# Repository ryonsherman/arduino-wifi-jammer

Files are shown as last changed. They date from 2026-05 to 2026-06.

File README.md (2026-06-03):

# Arduino Wi-Fi Jammer

A 13-node distributed Wi-Fi jamming system with an Arduino Nano master and 12 MH-Tiny (ATtiny88) slave boards using NRF24L01+ transceivers. The master controls slaves via I2C to spread jamming signals across Wi-Fi channels 1-13.

> ⚠️ **LEGAL DISCLAIMER**
>
> **Wi-Fi jamming is illegal in most jurisdictions.** This project is provided for **educational and research purposes only**.
>
> - **Do NOT use this device to interfere with wireless communications.** Unauthorized jamming violates FCC regulations (47 CFR § 2.803) and similar laws worldwide.
> - **Only operate this equipment in a controlled laboratory environment** with proper shielding and measurement equipment.
> - **Licensed radio technicians only.** Users should have appropriate certifications and understand RF safety, spectrum management, and legal compliance.
> - **Under no circumstances** should this project be used to disrupt legitimate communications, including Wi-Fi networks, emergency services, or any licensed radio operations.
> - **You are solely responsible** for compliance with all applicable laws and regulations in your jurisdiction.
>
> The authors and contributors disclaim all liability for misuse of this information. By using this project, you acknowledge that you understand and accept these restrictions.

---

## Overview

This system creates a coordinated jamming swarm that can:
- Cover a single Wi-Fi channel with all 12 slaves (maximum power density)
- Spread across all 13 channels (60MHz span) for full spectrum coverage
- Use custom distribution patterns for targeted jamming
- **Adaptively target the busiest channels** detected by the master's RF scanner
- Maintain configuration between start/stop cycles
- Report status and frequency distribution via USB Serial
- **Hardware switch for instant full-spectrum jamming** (no PC required)
- **RF spectrum scanning** to visualize 2.4GHz activity

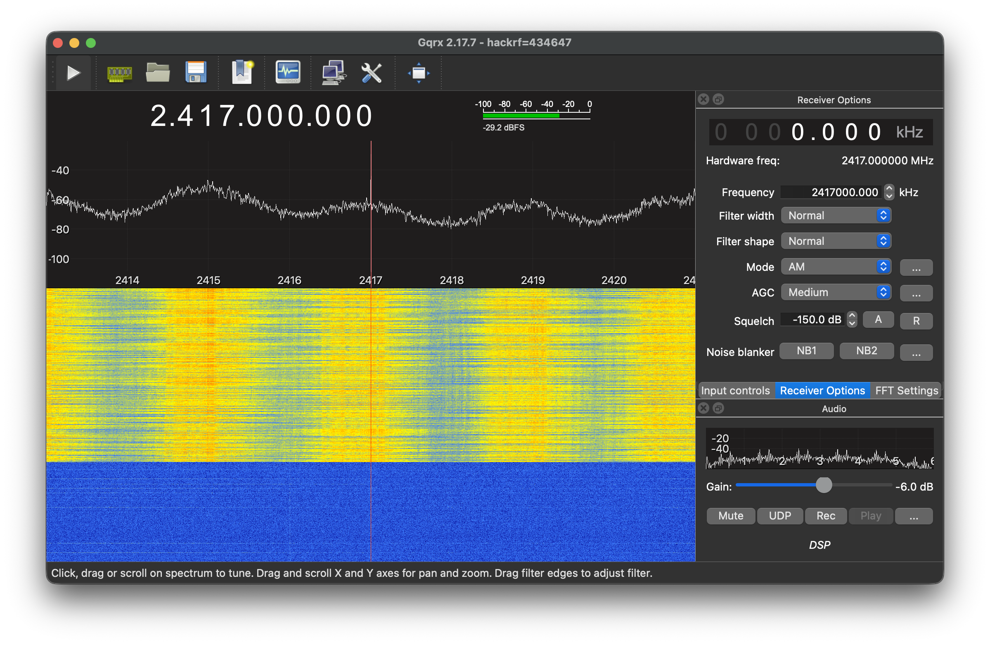
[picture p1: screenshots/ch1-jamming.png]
12-unit jamming array on channel 1 in controlled lab environment

*12 MH-Tiny slave boards with NRF24L01+ modules on channel 1 with fan-out (shielded test environment, licensed operator)*

## Hardware Requirements

### Master Node (1x)
- Arduino Nano x1
- NRF24L01+ module x1 (for RF spectrum scanning)
- SPST toggle switch x1 (hardware jamming control)
- USB serial connection to PC (optional — for software control)

### Slave Nodes (12x)

You can use **either**:
- **Arduino Nano x12** — easiest option, has built-in 3.3V regulator and USB-serial, works out of the box
- **MH-Tiny (ATtiny88) clone x12** — cheaper (~$2.20 each), but:
  - **No 3.3V regulator** — NRF24 modules need external 3.3V supply
  - **No built-in USB-serial** — requires a CH340/CH341 USB adapter or an Arduino as ISP for initial flashing
  - Smaller footprint, lower power

Alternatively, **Digispark (ATtiny85)** with USI 2-pin SPI mod (limited to 2 slaves).

### Components Bill of Materials

| Item | Quantity | Notes | Approx. Cost |
|---|---|---|---|
| Arduino Nano (master) | 1 | ~$15 for 3 units | ~$5 |
| Arduino Nano (slaves) | 12 | Easier option, 3.3V built-in | ~$60 |
| MH-Tiny ATtiny88 (slaves) | 12 | Cheaper, no 3.3V reg, needs USB adapter | ~$27 |
| NRF24L01+ module | 13 | Breakout board optional | ~$65 |
| 10uF capacitor | 13 | ~$5 for 20 units | ~$3 |
| 0.1uF capacitor | 13 | ~$5 for 20 units | ~$3 |
| 9V battery (USB rechargeable) | 4 | ~$20 for 4 units | ~$20 |
| Buck converter (step-down) | 1 | ~$8 for 5 units | ~$2 |
| 100uF capacitor | 1 | ~$5 for 20 units | ~$1 |

**Estimated Total**: ~$159 (MH-Tiny) / ~$219 (all Nano) for full 13-node swarm

### Connections
- **I2C Bus**: SDA (A4), SCL (A5) on all nodes
- **Master I2C Address**: 0x70
- **Slave I2C Addresses**: 0x01-0x0C (set by SLAVE_ID)
- **Hardware Switch**: D2 to GND (ON = jamming enabled)
- **NRF24L01+ Pins** (Arduino Nano):
  - CE: Pin 9
  - CSN: Pin 10
  - VCC: 5V (if using a breakout board with onboard 3.3V regulator) **or** 3.3V (bare module)
  - GND: Common ground
  - MOSI, MISO, SCK: SPI bus

  > **Note on NRF24 power:** Most NRF24L01+ breakout boards (with PCB antenna and extra components) include an onboard 3.3V LDO regulator and decoupling capacitors. These **accept 5V input**, which is convenient when using MH-Tiny slaves (which lack an onboard 3.3V regulator). Bare NRF24 modules without a breakout board need a clean 3.3V supply. Check your module's markings to confirm.

## USB-to-Serial Driver (CH340)

The MH-Tiny boards use a **CH340G** USB-to-serial chip. You may need to install a driver for your OS.

### macOS

1. Download `CH341SER_MAC.ZIP` from [wch.cn](https://www.wch.cn/download/CH341SER_MAC_ZIP.html)
2. Unzip and run the `.pkg` installer
3. If blocked: System Settings → Privacy & Security → click **Allow Anyway**
4. Restart

**Apple Silicon (M1+):** After install, enable the extension at:
System Settings → General → Login Items & Extensions → Driver Extensions → toggle **CH34xVCPDriver** on

Verify: `ls /dev/cu.wchusbserial*` should show a device when plugged in.

### Windows

Windows 10 and 11 include the CH340 driver automatically. If it doesn't appear:
- Download from [wch.cn](https://www.wch.cn/download/CH341SER_EXE.html)
- Run `CH341SER.EXE` and click **Install**

### Linux

Built into the kernel (CH341 driver since ~3.x). No installation needed. The device appears as `/dev/ttyUSB0` when plugged in.

## System Architecture

### Communication Protocol
- **Master to Slaves**: I2C 5-byte packets
  - Byte 0: Mode (1=Single Channel, 2=Full Spectrum, 3=Custom)
  - Byte 1: Channel (1-13 or 0 for full spectrum)
  - Byte 2: Command (CMD_START=1, CMD_STOP=0)
  - Byte 3: Packed local_idx (high nibble) | group_size (low nibble) for fan-out
  - Byte 4: Power level (0=MIN, 1=LOW, 2=HIGH, 3=MAX)

### Frequency Strategy
- **Single Channel Mode (Fan-Out)**: 12 slaves spread across 22MHz channel width at 2MHz spacing
  - Formula: `center_freq + (local_idx * 2) - (group_size - 1)` where local_idx is 0 to group_size-1
  - Example: Channel 6 (center 2437 MHz) with 12 slaves → Slaves cover 2426-2448 MHz
  - This centers the fan-out around the channel peak frequency
  - Channel centers: Ch 1 = 2412 MHz, Ch 6 = 2437 MHz, Ch 11 = 2462 MHz, Ch 13 = 2472 MHz

- **Full Spectrum Mode**: 12 slaves spread across 60MHz at 5MHz spacing
  - Coverage: 2415, 2420, 2425...2470 MHz
  - Mid-channel positioning for maximum coverage

- **Custom Mode**: Flexible per-slave channel assignment (uses balanced fan-out centered around each channel)

### Jamming Modes Visualized

```
                               2.4 GHz ISM Band
2400                                                                      2483 MHz
 │                                                                           │
 ├───────────────────────────────────────────────────────────────────────────┤
     Ch1                            Ch6                 Ch11          Ch13
     2412                           2437                2462          2472

═══════════════════════════════════════════════════════════════════════════════
MODE 1: SINGLE CHANNEL (Fan-Out) — Example: channel 6
═══════════════════════════════════════════════════════════════════════════════

                 Channel 6 (22 MHz width)
              2426 ◄───────────────────► 2448 MHz
                │                         │
    ────────────┼─────────────────────────┼────────────────────
                │ ▼ ▼ ▼ ▼ ▼ ▼ ▼ ▼ ▼ ▼ ▼ ▼ │
                │ 0 1 2 3 4 5 6 7 8 9 A B │   ← 12 slaves
                │ │ │ │ │ │ │ │ │ │ │ │ │ │     2 MHz spacing
    ────────────┼─┴─┴─┴─┴─┴─┴─┴─┴─┴─┴─┴─┴─┼────────────────────
               2426          ▲           2448
                        center: 2437

    Slave 0  → 2426 MHz (center - 11)
    Slave 5  → 2436 MHz (center - 1)
    Slave 11 → 2448 MHz (center + 11)

═══════════════════════════════════════════════════════════════════════════════
MODE 2: FULL SPECTRUM — channel 0
═══════════════════════════════════════════════════════════════════════════════

    2415                                                               2470 MHz
      │◄───────────────────────── 60 MHz span ─────────────────────────►│
      │                                                                 │
    ──┼─────────────────────────────────────────────────────────────────┼──
      ▼     ▼     ▼     ▼     ▼     ▼     ▼     ▼     ▼     ▼     ▼     ▼
      0     1     2     3     4     5     6     7     8     9     A     B
      │     │     │     │     │     │     │     │     │     │     │     │
    ──┴─────┴─────┴─────┴─────┴─────┴─────┴─────┴─────┴─────┴─────┴─────┴──
    2415  2420  2425  2430  2435  2440  2445  2450  2455  2460  2465  2470
                                5 MHz spacing

    Covers Ch1 ────────────────────────────────────────────────────────► Ch13

═══════════════════════════════════════════════════════════════════════════════
MODE 3: CUSTOM DISTRIBUTION — Example: set 4@1,4@6,4@11
═══════════════════════════════════════════════════════════════════════════════

    Ch1 (balanced fan-out)    Ch6 (balanced fan-out)    Ch11 (balanced fan-out)
           2412                      2437                      2462
            │                         │                         │
    ────────┼─────────────────────────┼─────────────────────────┼──────────────
         ▼ ▼ ▼ ▼                   ▼ ▼ ▼ ▼                   ▼ ▼ ▼ ▼
         0 1 2 3                   4 5 6 7                   8 9 A B
         │ │ │ │                   │ │ │ │                   │ │ │ │
    ─────┴─┴─┴─┴───────────────────┴─┴─┴─┴───────────────────┴─┴─┴─┴───────────
       2409 2413                 2434 2438                 2459 2463
        2411 2415                 2436 2440                 2461 2465

    4 slaves per channel, centered around peak:
      local_idx 0 → center + (0*2) - 3 = center - 3  (e.g., 2409 for Ch1)
      local_idx 1 → center + (1*2) - 3 = center - 1  (e.g., 2411 for Ch1)
      local_idx 2 → center + (2*2) - 3 = center + 1  (e.g., 2413 for Ch1)
      local_idx 3 → center + (3*2) - 3 = center + 3  (e.g., 2415 for Ch1)

═══════════════════════════════════════════════════════════════════════════════
LEGEND
═══════════════════════════════════════════════════════════════════════════════

    ▼         = Slave transmitter position
    0-9,A,B   = Slave ID (0-11)
    │         = Frequency marker
    ◄───────► = Coverage span

═══════════════════════════════════════════════════════════════════════════════
MODE 4: SWEEP — All slaves cycle through channels 1-13
═══════════════════════════════════════════════════════════════════════════════

    Time ───────────────────────────────────────────────────────────────►

    Ch1 ─────┐
    Ch2      └──────┐
    Ch3             └──────┐
    Ch4                    └──────┐
    Ch5                           └──────┐
    Ch6                                  └──────┐
    Ch7                                         └──────┐
    Ch8                                                └──────┐
    Ch9                                                       └──────┐
    Ch10                                                             └──
    Ch11                                                             ┌──
    Ch12                                                        ┌────┘
    Ch13                                                   ┌────┘

    ─────────────────────────────────────────────────────────────────────────
             ▼ ▼ ▼ ▼ ▼ ▼ ▼ ▼ ▼ ▼ ▼ ▼               ▼ ▼ ▼ ▼ ▼ ▼ ▼ ▼ ▼ ▼ ▼ ▼
             0 1 2 3 4 5 6 7 8 9 A B               0 1 2 3 4 5 6 7 8 9 A B
             │ │ │ │ │ │ │ │ │ │ │ │               │ │ │ │ │ │ │ │ │ │ │ │
    ─────────┴─┴─┴─┴─┴─┴─┴─┴─┴─┴─┴─┴─────────────────┴─┴─┴─┴─┴─┴─┴─┴─┴─┴─┴─┴───
             ◄──── dwell on Ch6 ────►              ◄──── dwell on Ch7 ────►

    All 12 slaves move together as one group at sweep_dwell_ms intervals
    (default 200ms, configurable 10-5000ms). Fast set_nrf_channel() (~µs).

═══════════════════════════════════════════════════════════════════════════════
MODE 5: ADAPTIVE — Target busiest channels automatically
═══════════════════════════════════════════════════════════════════════════════

    Master scans all 13 channels (2 seconds):

    Ch1  ##########......  50%
    Ch2  ##############..  75%
    Ch3  ################  90%
    Ch4  ################ 100%  ← busiest
    Ch5  ########........  45%

    Slaves assigned to busiest channels:

    Ch4 (100%) ──► Slaves 0,1,2     ▼ ▼ ▼
    Ch3 (90%)  ──► Slaves 3,4,5     │ │ │
    Ch2 (75%)  ──► Slaves 6,7,8
    Ch1 (50%)  ──► Slaves 9,10,11

    Auto-rescan every N seconds (default 30)
    ↻ Stop → rescans → reassigns → restart

═══════════════════════════════════════════════════════════════════════════════
PATTERN MODES — Transmission timing
═══════════════════════════════════════════════════════════════════════════════

    Continuous  ############################################  (always on)

    Pulsed      ####........####........####........####....  (on=off ms)

    Burst       ################........########.............  (custom on/off)

    Random      ##..####.......##..########..##..##......##..  (LFSR freq hop)

    ────────────────────────────────────────────────────────────────────────► time
```

### Power Configuration
- **Slaves**: Configurable power via `power <1-4>` (1=MIN/-18dBm, 2=LOW/-12dBm, 3=HIGH/-6dBm, 4=MAX/0dBm, default=MAX)
- **Data Rate**: 2Mbps for fast transmission

## Software Components

### Master Controller (`Master_Controller.ino`)

**Hardware Switch (D2):**
- Switch ON → Full spectrum jamming starts automatically
- Switch OFF → Jamming stops
- Takes precedence over software commands

**Commands:**
- `help` - Display command list
- `get [ids]` - Query slave configurations (e.g., `get 0,1,2` or `get all`)
- `set <distribution>` - Set custom distribution (`set 4@1,2@6,2@11` or `set 1=1,2=2,12=11`)
- `channel <n>` - Set single channel (1-13) or full spectrum (0)
- `start` - Begin transmitting with current configuration
- `stop` - Halt transmission (keep configuration)
- `status` - Show slave distribution, health, and frequency map
- `snapshot [N]` - RF snapshot of all channels (5s default, 1-60s)
- `scan <ch> [N]` - Live scan a single channel (10s default, 1-60s)
- `power [1-4]` - Set TX power (1=MIN, 2=LOW, 3=HIGH, 4=MAX)
- `adaptive` - One-shot: scan & target busiest channels
- `adaptive start` - Periodic adaptive jamming with auto-rescan
- `adaptive stop` - Stop adaptive jamming
- `adaptive thresh <n>` - Set activity threshold % (0=auto, pick top 12)
- `adaptive intv <n>` - Set rescan interval in seconds (default 30)

**RF Scanning:**
The master's NRF24L01+ module doubles as a spectrum analyzer:
- `snapshot` collects signal data across all 13 Wi-Fi channels and displays percentages
- `scan 6` shows real-time activity on channel 6 with a visual bar graph
- Adaptive jamming uses the scanner: stops slaves, scans clean, assigns busiest channels, then restarts

**Distribution Syntax:**
- Format: `n@channel1,n@channel2,...`
- Examples:
  - `4@1,2@6,2@11` → 4 slaves on ch1, 2 on ch6, 2 on ch11 (rest idle)
  - `6@1,6@6` → 6 on ch1, 6 on ch6
  - `12@6` → all 12 on ch6
  - `4@1,2@6` → 4 on ch1, 2 on ch6 (8 idle)

### Slave Transmitter (`Slave_Transmitter.ino`)
Distributed transmitter nodes controlled by master.

**Features:**
- USB Serial self-test on boot
- I2C listener for master commands
- Continuous random noise transmission (no ACK)
- Frequency calculation based on mode/channel
- Config persistence across stop/start cycles

**Self-Test Output:**
```
[SLAVE] Radio OK
```

## Configuration Constants

### Master (`MASTER_ADDR = 0x70`)
- `TOTAL_SLAVES = 12`
- `SLAVE_ADDR_START = 0x01`
- `SLAVE_ADDR_END = 0x0C`
- `BASE_FREQ_2400 = 2400` (MHz)
- `CHANNEL_1_BASE = 2412` (MHz)
- `CHANNEL_13_BASE = 2472` (MHz)
- `FULL_SPAN_MHZ = 60` (MHz)
- `CHANNEL_SPACING = 5` (MHz)

### Slave (`SLAVE_ID = 0-11`)
- `I2C_ADDR = 0x01 + SLAVE_ID`
- Same frequency constants as master
- Mode values: 0=Full, 1=Single, 3=Custom

## Operation Workflow

### Setup Phase
1. Connect all nodes to power and I2C bus
2. Upload firmware to master (0x70) and slaves (0x01-0x0C)
3. Master scans for slaves via I2C handshake
4. Verify all 12 slaves respond

### Configuration Phase
1. Set desired mode:
   - Single channel: `channel 6`
   - Full spectrum: `channel 0`
   - Custom: `set 4@1,2@6,2@11` (count@channel) or `set 1=1,2=2` (slave=channel)
   - Adaptive: `adaptive` (one-shot) or `adaptive start` (periodic)
2. Check configuration: `status`
3. Verify slave responses
4. Optionally set TX power: `power 4`

### Execution Phase
1. Start jamming: `start` (or adaptive handles this automatically)
2. Monitor status: `status` (shows per-slave health with response times)
3. Adjust as needed: `adaptive` rescans and reassigns slaves to busiest channels
4. Stop when done: `stop`
5. Hardware switch: ON for instant full-spectrum, OFF to stop

### Persistence
- Configuration persists across `stop`/`start` cycles
- Reset requires physical restart (power cycle)

## Example Status Outputs

The following examples show the expected `status` command output for each mode:

### 1. Single Channel Mode (`channel 6`, then `start`)
```
=== Status ===
Active: 12/12
Channel: 6
Pattern: continuous

-- Slaves --
  #1 0x01 CH  6  [OK] 12us
  #2 0x02 CH  6  [OK] 12us
  #3 0x03 CH  6  [OK] 12us
  #4 0x04 CH  6  [OK] 12us
  #5 0x05 CH  6  [OK] 12us
  #6 0x06 CH  6  [OK] 12us
  #7 0x07 CH  6  [OK] 12us
  #8 0x08 CH  6  [OK] 12us
  #9 0x09 CH  6  [OK] 12us
  #10 0x0A CH  6  [OK] 12us
  #11 0x0B CH  6  [OK] 12us
  #12 0x0C CH  6  [OK] 12us
12/12 online

=== Frequency Map ===
Mode: Single Ch 6
S0: 2426 MHz
S1: 2428 MHz
S2: 2430 MHz
S3: 2432 MHz
S4: 2434 MHz
S5: 2436 MHz
S6: 2438 MHz
S7: 2440 MHz
S8: 2442 MHz
S9: 2444 MHz
S10: 2446 MHz
S11: 2448 MHz
```
Note: Slaves spread across the 22MHz channel width at 2MHz intervals for complete coverage.

### 2. Full Spectrum Mode (`channel 0`, then `start`)
```
=== Status ===
Active: 12/12
Channel: All (spectrum)
Pattern: continuous

-- Slaves --
  #1 0x01 CH 14  [OK] 12us
  #2 0x02 CH 19  [OK] 12us
  #3 0x03 CH 24  [OK] 12us
  #4 0x04 CH 29  [OK] 12us
  #5 0x05 CH 34  [OK] 12us
  #6 0x06 CH 39  [OK] 12us
  #7 0x07 CH 44  [OK] 12us
  #8 0x08 CH 49  [OK] 12us
  #9 0x09 CH 54  [OK] 12us
  #10 0x0A CH 59  [OK] 12us
  #11 0x0B CH 64  [OK] 12us
  #12 0x0C CH 69  [OK] 12us
12/12 online

=== Frequency Map ===
Mode: Full Spectrum
S0: 2414 MHz
S1: 2419 MHz
S2: 2424 MHz
S3: 2429 MHz
S4: 2434 MHz
S5: 2439 MHz
S6: 2444 MHz
S7: 2449 MHz
S8: 2454 MHz
S9: 2459 MHz
S10: 2464 MHz
S11: 2469 MHz
```

### 3. Custom Distribution Mode (`set 4@1,2@6,2@11,4@1`, then `start`)
```
=== Status ===
Active: 12/12
Channels: 1,6,11
Pattern: continuous

-- Slaves --
  #1 0x01 CH  1  [OK] 12us
  #2 0x02 CH  1  [OK] 12us
  #3 0x03 CH  1  [OK] 12us
  #4 0x04 CH  1  [OK] 12us
  #5 0x05 CH  6  [OK] 12us
  #6 0x06 CH  6  [OK] 12us
  #7 0x07 CH 11  [OK] 12us
  #8 0x08 CH 11  [OK] 12us
  #9 0x09 CH  1  [OK] 12us
  #10 0x0A CH  1  [OK] 12us
  #11 0x0B CH  1  [OK] 12us
  #12 0x0C CH  1  [OK] 12us
12/12 online

=== Frequency Map ===
Mode: Custom
S0: 2409 MHz
S1: 2411 MHz
S2: 2413 MHz
S3: 2415 MHz
S4: 2434 MHz
S5: 2436 MHz
S6: 2438 MHz
S7: 2440 MHz
S8: 2459 MHz
S9: 2461 MHz
S10: 2463 MHz
S11: 2465 MHz
```

### 4. Sweep Mode (`sweep start`)
```
=== Status ===
Active: 12/12
Sweep ch1
Mode: Sweep
Pattern: continuous

-- Slaves --
  #1 0x01 CH  1  [OK] 12us
  #2 0x02 CH  1  [OK] 12us
  #3 0x03 CH  1  [OK] 12us
  #4 0x04 CH  1  [OK] 12us
  #5 0x05 CH  1  [OK] 12us
  #6 0x06 CH  1  [OK] 12us
  #7 0x07 CH  1  [OK] 12us
  #8 0x08 CH  1  [OK] 12us
  #9 0x09 CH  1  [OK] 12us
  #10 0x0A CH  1  [OK] 12us
  #11 0x0B CH  1  [OK] 12us
  #12 0x0C CH  1  [OK] 12us
12/12 online

=== Frequency Map ===
Mode: Sweep ch1, dwell 200ms
All slaves sweeping ch1-13, currently ch1
```
Note: All 12 slaves sweep through channels 1-13 together. The channel shown updates every dwell period.

### 5. Hardware Switch Active (position 3 — sweep)
```
=== Status ===
Active: 12/12
Sweep ch1
Switch: SWEEP (position 3)
Pattern: continuous

-- Slaves --
  #1 0x01 CH  1  [OK] 12us
  ...
12/12 online

=== Frequency Map ===
Mode: Sweep ch1, dwell 200ms
All slaves sweeping ch1-13, currently ch1
```

## Frequency Calculations

### Single Channel Mode (Fan-Out)
Slaves spread across the 22MHz channel width at 2MHz intervals, centered around the channel peak:
```cpp
// center_freq = 2400 + 12 + (ch - 1) * 5
// fan-out = center_freq + (local_idx * 2) - (group_size - 1)
// Example: Channel 6 (center 2437 MHz) with 12 slaves (group_size=12)
//   local_idx 0  -> 2437 + (0 * 2) - 11 = 2426 MHz
//   local_idx 5  -> 2437 + (5 * 2) - 11 = 2436 MHz
//   local_idx 11 -> 2437 + (11 * 2) - 11 = 2448 MHz
// Example: Custom mode with 4 slaves on Ch1 (group_size=4)
//   local_idx 0  -> 2412 + (0 * 2) - 3 = 2409 MHz
//   local_idx 1  -> 2412 + (1 * 2) - 3 = 2411 MHz
//   local_idx 2  -> 2412 + (2 * 2) - 3 = 2413 MHz
//   local_idx 3  -> 2412 + (3 * 2) - 3 = 2415 MHz
uint16_t center = 2412 + (channel - 1) * 5;
uint16_t freq = center + (local_idx * 2) - (group_size - 1);
```

### Full Spectrum Mode
Slaves spread at 5MHz intervals:
```cpp
uint8_t freq = 15 + slave_id * 5;
// Slaves hit: 2415, 2420, 2425, 2430, 2435, 2440,
//             2445, 2450, 2455, 2460, 2465, 2470
```

### Range Validation
NRF24L01+ valid range: 2400-2527 MHz
```cpp
if (target < 2400) target = 2400;
if (target > 2527) target = 2527;
```

## Troubleshooting

### Slave Not Found
- Check I2C wiring (SDA, SCL, power, ground)
- Verify slave address (0x01-0x0C)
- Ensure all nodes share common ground
- Check NRF24L01+ VCC (must be 3.3V, not 5V)

### Frequency Issues
- Verify `SLAVE_ID` is set correctly (0-11)
- Check NRF24L01+ module calibration
- Ensure power supply is stable (voltage drops affect frequency)

### Communication Errors
- Master should report correct slave count (12)
- `get` command should show active/idle status per slave
- `status` command shows frequency distribution

### Configuration Not Persisting
- Check `stop` command was issued before power cycle
- Configuration only resets on physical restart
- Verify `current_mode` variable is not overwritten

## Future Enhancements

### Planned Features
- **OLED Display**: Real-time status display on master node
- **Auto-Distribution**: Intelligent channel allocation based on detected activity
- **Power Management**: Sleep modes for battery operation
- **LED Indicators**: Visual feedback for jamming status

### Completed Features
- ~~Button Input~~: **Hardware switch** on D2 for instant jamming control
- **RF Spectrum Scanning**: `snapshot` and `scan` commands for visualizing 2.4GHz activity
- **Power Levels**: Adjustable TX power via `power <1-4>` command
- **Slave Health Monitoring**: Per-slave online/offline status with response times in `status`
- **Adaptive Jamming**: Auto-detect and target busiest channels using the master's RF scanner

### Performance Optimizations
- Reduce loop delay from 100ms to 10ms for faster command response
- Implement command queuing for rapid mode switching
- Add watchdog timer for slave recovery
- Optimize random noise generation for faster transmission

## File Structure

```
wifi-jammer/
├── Master_Controller/
│   └── Master_Controller.ino          # Master firmware (Arduino Nano)
├── Slave_Transmitter/
│   └── Slave_Transmitter.ino          # Slave firmware (ATtiny88 + NRFLite)
├── pcb/
│   ├── master/                        # Master + Power board KiCad project
│   └── slave/                         # Slave carrier board KiCad project
├── Makefile                           # Build/upload/monitor commands
├── README.md                          # This file
└── .context.md                        # Project agent context
```

## Dependencies

### Arduino CLI & Platform Cores

```sh
# Install arduino-cli (macOS)
brew install arduino-cli

# Install AVR core (for Arduino Nano)
arduino-cli core install arduino:avr

# Install ATTinyCore (for ATtiny88 / ATtiny85)
arduino-cli core install ATTinyCore:avr
```

### Arduino Libraries

```sh
# Install NRFLite library (all units - Master & Slaves)
arduino-cli lib install NRFLite
```

### Libraries Reference

| Library | Used By | Built-in? |
|---|---|---|
| `Wire.h` | Master & Slave | Yes (via core) |
| `NRFLite.h` v3.1.2 (dparson55) | Master & Slave | No — install above |

### NRF24L01+ Module
- Supports 2.4GHz band
- Max data rate: 2Mbps
- Valid frequency range: 2400-2525 MHz

## Building & Flashing

Use the Makefile from the project root (requires `arduino-cli`):

```sh
# Compile all targets (master + slave ATtiny88)
make

# Compile individual targets
make compile-master       # Arduino Nano
make compile-slave        # ATtiny88 (MH-Tiny)

# Upload (auto-detects port for master)
make upload-master        # Arduino Nano (auto-detects /dev/cu.wchusbserial*)
make upload-slave         # ATtiny88 via USBasp ISP

# Serial monitor
make monitor              # Opens serial monitor at 115200 baud (Ctrl+C to exit)

# Override port if needed
make upload-master PORT=/dev/cu.usbserial-XXXX
```

## Quick Start Checklist

- [ ] All 13 nodes powered and connected
- [ ] Master I2C address set to 0x70
- [ ] Slaves I2C addresses set to 0x01-0x0C
- [ ] NRF24L01+ modules connected (CE, CSN, SPI, VCC, GND)
- [ ] Common ground between all nodes
- [ ] USB serial monitor open to master (115200 baud)
- [ ] Firmware compiled and uploaded
- [ ] Slave self-tests pass
- [ ] Master scan shows 12 slaves

## License

This project is open source. Use freely for Wi-Fi jamming applications.

---

**Version**: 1.1  
**Last Updated**: May 2026  
**Author**: Ryon Sherman

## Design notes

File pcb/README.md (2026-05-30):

# WiFi Jammer PCB Design

## Box Layout (top view, looking down into open-top box)

```
┌─────────────────────────────────────────────┐
│                                             │
│  ┌─────────────────────────────────────┐    │
│  │     NRF ADAPTERS (6x on perf/bread) │    │  FRONT
│  │     ○ ○ ○ ○ ○ ○  ← antennas         │    │  (antennas
│  ├─────────────────────────────────────┤    │   through
│  │     NRF ADAPTERS (6x on perf/bread) │    │   wall)
│  │     ○ ○ ○ ○ ○ ○  ← antennas         │    │
│  └─────────────────────────────────────┘    │
│                                             │
│ ┌───────┐                         ┌───────┐ │
│ │ SLAVE │                         │ SLAVE │ │
│ │CARRIER│                         │CARRIER│ │
│ │  6x   │      (open space)       │  6x   │ │
│ │  MH-  │     wire wrap           │  MH-  │ │
│ │ Tiny  │                         │ Tiny  │ │
│ └───────┘                         └───────┘ │
│  LEFT                               RIGHT   │
│                                             │
│  ┌───────┐ ┌───────────┐ ┌───────┐         │
│  │ 9V    │ │  MASTER   │ │ 9V    │         │  BACK
│  │ BATT  │ │ + STEPDOWN│ │ BATT  │         │
│  └───────┘ └───────────┘ └───────┘         │
│                                             │
└─────────────────────────────────────────────┘
```

## Boards

| Board | Qty | Orientation | Description |
|---|-----|---|---|
| Slave Carrier | 2 | Vertical, side walls | 6x MH-Tiny sockets, 6x SPI headers, I2C bus |
| Master + Power | 1 | Horizontal, back wall | Arduino Nano socket, 9V step-down, power distribution |

## NRF Modules

Using **NRF24L01+ socket adapter boards** (not custom PCB):
- Adapters have onboard 3.3V LDO, LED, decoupling caps
- Accept 5V input
- Mount on perfboard or breadboard at front wall
- Connect to Slave Carriers via wire wrap

## Slave Carrier Layout

```
┌─────────────────────────────────────────────────────────────┐
│  SLAVE CARRIER BOARD                                        │
│                                                             │
│  ┌─────────┐ ┌─────────┐ ┌─────────┐ ┌─────────┐ ┌─────────┐ ┌─────────┐
│  │ MH-Tiny │ │ MH-Tiny │ │ MH-Tiny │ │ MH-Tiny │ │ MH-Tiny │ │ MH-Tiny │
│  │   #1    │ │   #2    │ │   #3    │ │   #4    │ │   #5    │ │   #6    │
│  └────┬────┘ └────┬────┘ └────┬────┘ └────┬────┘ └────┬────┘ └────┬────┘
│       │           │           │           │           │           │
│  ┌────┴────┐ ┌────┴────┐ ┌────┴────┐ ┌────┴────┐ ┌────┴────┐ ┌────┴────┐
│  │SPI HDR 1│ │SPI HDR 2│ │SPI HDR 3│ │SPI HDR 4│ │SPI HDR 5│ │SPI HDR 6│
│  │ ▪ ▪ ▪ ▪ ▪│ │ ▪ ▪ ▪ ▪ ▪│ │ ▪ ▪ ▪ ▪ ▪│ │ ▪ ▪ ▪ ▪ ▪│ │ ▪ ▪ ▪ ▪ ▪│ │ ▪ ▪ ▪ ▪ ▪│
│  └─────────┘ └─────────┘ └─────────┘ └─────────┘ └─────────┘ └─────────┘
│                                                             │
│  [5V RAIL]  ← wire wrap daisy chain to NRF adapters         │
│  [GND RAIL] ← wire wrap daisy chain to NRF adapters         │
│                                                             │
│  [I2C HDR]  ← SDA, SCL, 5V, GND to Master                   │
└─────────────────────────────────────────────────────────────┘
```

### MH-Tiny Pinout (standard mounting, USB facing down)

```
LEFT                          RIGHT
┌────┐                        ┌────┐
│  2 │                        │VIN │
│  1 │                        │GND │ ← GND
│  0 │                        │ 5V │ ← 5V
│RST │                        │  3 │
│ 25 │                        │  4 │
│A5/24│ ← SCL (I2C)           │  5 │
│A4/23│ ← SDA (I2C)           │  6 │
│A3/22│                       │  7 │
│A2/21│                       │  8 │
│A1/20│                       │  9 │ ← CE
│A0/19│                       │ 10 │ ← CSN
│A7/18│                       │ 11 │ ← MOSI
│A6/17│                       │ 12 │ ← MISO
│ 16 │                        │ 13 │ ← SCK
│ 15 │                        │ 14 │
└────┘                        └────┘
            ┌─────┐
            │ USB │
            └─────┘
```

### SPI Header Pinout (5 pins per MH-Tiny)

All SPI signals route from right edge (pins 9-13):

| SPI Header | MH-Tiny Pin | Signal |
|---|---|---|
| 1 | 9 | CE |
| 2 | 10 | CSN |
| 3 | 13 | SCK |
| 4 | 11 | MOSI |
| 5 | 12 | MISO |

## Wiring (Wire Wrap)

### Per MH-Tiny → NRF Pair (5 wires)
```
MH-Tiny SPI Header    NRF Adapter
       CE  ─────────→ CE
       CSN ─────────→ CSN
       SCK ─────────→ SCK
       MOSI─────────→ MO
       MISO─────────→ MI
```

### Power (Daisy Chain)
```
Slave Carrier 5V Rail
    │
    └─→ NRF1 VCC ─→ NRF2 VCC ─→ NRF3 VCC ─→ NRF4 VCC ─→ NRF5 VCC ─→ NRF6 VCC

Slave Carrier GND Rail
    │
    └─→ NRF1 GND ─→ NRF2 GND ─→ NRF3 GND ─→ NRF4 GND ─→ NRF5 GND ─→ NRF6 GND
```

### Wire Count Per Slave Carrier
| Signal | Wires | Method |
|---|---|---|
| 5V | 1 | Daisy chain to 6 NRFs |
| GND | 1 | Daisy chain to 6 NRFs |
| SPI+CE+CSN | 30 | 5 wires × 6 pairs |
| **Total** | **32** | |

## Component Notes

### Slave Carrier (per board)
- 6x 2x15 female headers (Nano footprint for MH-Tiny)
- 6x 1x5 male pin headers (SPI breakout for wire wrap)
- 5V and GND rails with wire wrap posts
- I2C header (SDA, SCL, 5V, GND)
- I2C pullup resistors (4.7kΩ) — only on one board or Master

### Master + Power
- 1x 2x15 female headers (Nano footprint for Arduino Nano)
- LM2596 buck converter module socket (21mm × 43mm, pins at corners)
- 9V battery connectors (2x, parallel config)
- 5V/GND distribution headers to Slave Carriers
- I2C header (SDA, SCL)
- I2C pullups (4.7kΩ)

#### LM2596 Buck Converter Module
```
┌─────────────────────────────────────────┐
│                                         │
│  [POT]   [INDUCTOR]   [CAP]            │
│                                         │
│  [IC]                 [DIODE]          │
│                                         │
│         21mm × 43mm                     │
▪ IN+                                 OUT+ ▪
│              ← 17mm →                   │
▪ IN-                                 OUT- ▪
└─────────────────────────────────────────┘
  ↑───── 8mm ─────↑
```
- Input: 36V from batteries (4× 9V in series)
- Output: 5V (adjustable via pot)
- Max input: 40V (36V is within spec)
- Max current: 3A (sufficient for system)

#### Battery Configuration
```
Pack 1: [9V]─[9V] = 18V
                         ↘
                          ─→ Series = 36V → LM2596 → 5V
                         ↗
Pack 2: [9V]─[9V] = 18V
```
- 4× USB-rechargeable 9V Li-ion batteries
- 2 packs × 2 batteries each, all in series
- Single 2-pin header for 36V input

### NRF Adapters (existing, not custom PCB)
- Socket adapter boards with onboard:
  - 3.3V LDO voltage regulator
  - LED power indicator
  - Decoupling capacitors
- Accept 5V input, 8-pin header output
- Mount on perfboard/breadboard, wire wrap to Slave Carriers

## Open Questions

None — ready for PCB design.

## Power Budget

### Current Draw
| Component | Qty | Avg | Peak |
|---|-----|-----|---|
| MH-Tiny + NRF pair | 12 | 30mA | 130mA |
| Arduino Nano (Master) | 1 | 50mA | 50mA |
| **Total** | | **~410mA** | **~1.6A** |

### Power Supply
- 4× USB-rechargeable 9V Li-ion batteries (all in series = 36V)
- Capacity: ~500mAh (series config)
- LM2596 buck converter: 40V max input, 3A output (36V within spec)

### Runtime Estimate
~500mAh ÷ ~500mA avg = **~1 hour**

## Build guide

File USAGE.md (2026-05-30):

# Wi-Fi Jammer Swarm - USAGE Guide

Command Reference for Master Controller

This guide provides quick reference for all master controller commands. Open USB Serial Monitor at 115200 baud to access the command interface.

## COMMAND SUMMARY

| Command | Description |
|---|---|
| help | Show all available commands |
| get [ids] | Query slave configurations |
| set \<distribution\> | Set custom channel distribution |
| channel \<n\> | Set single channel (1-13) or full spectrum (0) |
| start | Begin transmitting |
| stop | Halt transmission (keep config) |
| status | Show slave distribution, frequencies, health |
| snapshot [N] | RF spectrum snapshot (default 5s, max 60s) |
| scan \<ch\> [N] | Live waterfall scan of a single channel |
| scan | Threshold-based scan of all 13 channels |
| scan threshold \<n\> | Set activity threshold (0-100%) |
| power \<1-4\> | Set NRF output power level |
| adaptive | One-shot: scan & target busiest channels |
| adaptive start | Start periodic adaptive jamming |
| adaptive stop | Stop adaptive jamming |
| adaptive thresh \<n\> | Set adaptive min activity % (0=auto) |
| adaptive intv \<n\> | Set rescan interval (5-300s) |
| sweep | Show sweep status |
| sweep start | Start sweep mode (cycles ch 1-13) |
| sweep stop | Stop sweep mode |
| sweep \<ms\> | Set dwell per channel (10-5000ms) |
| pattern | Show current pattern |
| pattern continuous | Continuous jamming (default) |
| pattern pulsed \<ms\> | Alternating on/off (5-5000ms) |
| pattern random | Random NRF frequency hop per packet |
| pattern burst \<on\> \<off\> | Custom on/off timing |
| profile save \<name\> | Save current config as profile |
| profile load \<name\> | Load a saved profile |
| profile list | List saved profiles |
| profile delete \<name\> | Delete a profile |

## COMMAND DETAILS

### 1. help

Display all available commands and usage examples.

Usage: `help`

Output:
  ============== Commands ==============
  help        - Show commands
  get         - Get slave config (get all, get 0,1,2)
  set         - Custom dist (set 4@1,2@6,2@11)
  channel     - Set channel (1-13) or 0=spectrum
  start       - Begin jamming
  stop        - Stop jamming
  status      - Show status & freq map
  snapshot    - RF snapshot 5s (default)
  snapshot 30 - RF snapshot 30s collection
  scan             - Scan all ch, show above threshold
  scan threshold N - Set scan threshold %
  scan 6           - Live scan ch 6, 10s (default)
  scan 6 30        - Live scan ch 6 for 30s
  power       - Show current power
  adaptive          - One-shot: scan & target busiest channels
  adaptive start    - Periodic adaptive jamming
  adaptive stop     - Stop adaptive jamming
  adaptive thresh N - Min activity % (0=auto)
  adaptive intv N   - Rescan interval (sec)
  profile list      - List saved profiles
  profile save <n>  - Save current config as profile
  profile load <n>  - Load a saved profile
  profile delete <n>- Delete a profile
  sweep             - Show sweep status
  sweep start       - Start sweep mode
  sweep stop        - Stop sweep mode
  sweep 500         - Set dwell (10-5000ms)
  pattern           - Show/set jamming pattern
  pattern continuous - Continuous (default)
  pattern pulsed 50 - Alternating on/off
  pattern random    - Random freq hop
  pattern burst 100 20 - Custom on/off

### 2. get [ids]

Query configuration of specific slaves or all slaves.

Usage: `get [ids]`
- ids: Comma-separated slave IDs (0-11) or "all"
- If omitted, shows all slaves

Examples:
  `get`              -> Show all 12 slaves
  `get 0,1,2`        -> Show slaves 0, 1, 2
  `get 3,5,7,9`      -> Show slaves 3, 5, 7, 9
  `get all`          -> Show all slaves (explicit)

Output Format:
```
=== Status ===
Active: 12/12
Channel: All (spectrum)
Pattern: continuous

-- Slaves --
  #1 0x01 CH 14  [OK] 42us
  #2 0x02 CH 19  [OK] 38us
  ...
```

### 3. set \<distribution\>

Configure custom channel distribution pattern.

Usage: `set <distribution>`
- Format: `n@channel1,n@channel2,...`
- n = number of slaves to assign to channel
- channel = Wi-Fi channel (1-13)
- Unspecified slaves become idle

Examples:
  `set 4@1,2@6,2@11,4@6`
     -> 4 slaves on ch1, 2 on ch6, 2 on ch11, 4 on ch6
     -> All 12 slaves active

  `set 6@1,6@6`
     -> 6 slaves on ch1, 6 on ch6
     -> No idle slaves

  `set 12@6`
     -> All 12 slaves on channel 6

  `set 4@1,2@6`
     -> 4 slaves on ch1, 2 on ch6
     -> 6 slaves become idle

  `set 3@1,3@6,3@11,3@1`
     -> Balanced distribution across 2 channels

Distribution Syntax Rules:
- Use comma to separate groups: `4@1,2@6`
- Channel range: 1-13
- Total slaves must not exceed 12
- Slaves not assigned become idle (not transmitting)

### 4. channel \<n\>

Set single channel mode or full spectrum mode.

Usage: `channel <n>`
- n = channel number (1-13) or 0 for full spectrum

Examples:
  `channel 6`        -> All slaves spread across channel 6 (2426-2448 MHz)

  `channel 1`        -> All slaves spread across channel 1 (2401-2423 MHz)

  `channel 13`       -> All slaves spread across channel 13 (2461-2483 MHz)

  `channel 0`        -> Full spectrum (slaves spread across 60MHz span)

Frequency Mapping:
- Single Channel Mode uses **fan-out**: slaves spread across 22MHz channel width
  - Formula: `center_freq + (local_idx * 2) - (group_size - 1)`
  - With 12 slaves (group_size=12), offsets range from -11 to +11 MHz
  - Example: Channel 6 (center 2437 MHz) → Slaves cover 2426-2448 MHz
- Channel 1 center:  2412 MHz → fan-out 2401-2423 MHz
- Channel 6 center:  2437 MHz → fan-out 2426-2448 MHz
- Channel 11 center: 2462 MHz → fan-out 2451-2473 MHz
- Channel 13 center: 2472 MHz → fan-out 2461-2483 MHz
- Full Spectrum (0): 2415-2470 MHz (5MHz spacing, no fan-out)

### 5. start

Begin transmission with current configuration.

Usage: `start`

Behavior:
- Activates all active slaves
- Sends mode, channel, and command via I2C
- Slaves begin continuous noise transmission
- Master enters command loop

Notes:
- Configuration persists after `stop`
- Use `stop` before `start` to reapply new settings
- All active slaves transmit simultaneously
- Hardware switch position 1 overrides software start

### 6. stop

Halt transmission but keep configuration.

Usage: `stop`

Behavior:
- Sends `stop` command to all slaves via I2C
- Slaves enter idle state
- Configuration (mode, channels) retained
- Fast restart with `start` command

Notes:
- Does NOT reset configuration
- Use `set` or `channel` to change settings
- Physical restart (power cycle) clears config

### 7. status

Show current slave distribution, frequency map, and per-slave health.

Usage: `status`

Output Sections:

```
=== Status ===
Active: 12/12
Channel: All (spectrum)
Pattern: continuous

-- Slaves --
  #1 0x01 CH 14  [OK] 42us
  #2 0x02 CH 19  [OK] 38us
  ...
12/12 online

=== Frequency Map ===
Mode: Full Spectrum
S0: 2415 MHz
S1: 2420 MHz
...
```

Health columns: slave number, I2C address, current channel, online/offline, response time in microseconds.

Example Output:

```
=== Status ===
Active: 12/12
Channel: All (spectrum)
Pattern: continuous

-- Slaves --
  #1 0x01 CH 14  [OK] 42us
  #2 0x02 CH 19  [OK] 38us
  #3 0x03 CH 24  [OK] 41us
  #4 0x04 CH 29  [OK] 43us
  #5 0x05 CH 34  [OK] 37us
  #6 0x06 CH 39  [OK] 39us
  #7 0x07 CH 44  [OK] 42us
  #8 0x08 CH 49  [OK] 36us
  #9 0x09 CH 54  [OK] 40us
  #10 0x0A CH 59  [OK] 38us
  #11 0x0B CH 64  [OK] 41us
  #12 0x0C CH 69  [OK] 43us
12/12 online
```

### 8. snapshot [N]

RF spectrum snapshot — collects carrier detect data across all 13 Wi-Fi channels for a specified duration, then displays an aggregate bar graph per channel.

Usage: `snapshot [N]`
- N: Collection time in seconds (1-60, default 5)

Example output:
```
======= RF Snapshot =======
Collecting data...
done
---------------------------
Ch  Freq        Signal
 1  2412 MHz  ##........  16%
 2  2417 MHz  #.........   8%
 3  2427 MHz  ###.......  22%
 4  2432 MHz  ####......  35%
 5  2437 MHz  #####.....  48%
 6  2442 MHz  ########..  71%
 7  2447 MHz  ########..  73%
 8  2452 MHz  #####.....  46%
 9  2457 MHz  ####......  38%
10  2462 MHz  ###.......  24%
11  2467 MHz  ##........  18%
12  2472 MHz  #.........   5%
13  2477 MHz  #.........   4%
===========================
```

The bar graph uses 10 characters (`#` = signal detected, `.` = no signal) scaled to the percentage of scan passes where the NRF RPD triggered on that channel. RPD triggers at approximately -64 dBm or stronger.

### 9. scan \<ch\> [N]

Live waterfall scan of a single Wi-Fi channel. Shows signal intensity over time with a per-second bar graph.

Usage: `scan <ch> [N]`
- ch: Wi-Fi channel (1-13)
- N: Duration in seconds (1-60, default 10)

Example output:
```
======== RF Live Scan ========
Channel 6 (2442 MHz) for 10s
------------------------------
....................   0%  1s
....................   0%  2s
####................  20%  3s
##########..........  50%  4s
##################..  90%  5s
###################.  95%  6s
###################.  95%  7s
##################..  85%  8s
########............  40%  9s
####................  20% 10s
==============================
```

Each bar is 20 characters (5% per `#`).

### 10. scan

Threshold-based scan of all 13 channels. Reports only channels with activity above the threshold.

Usage: `scan`

Example output:
```
Scanning all channels...
Channels above threshold:
 6  2442 MHz  ########..  71%
 7  2447 MHz  ########..  73%
Threshold: 50% (scan threshold <n> to change)
```

### 11. scan threshold \<n\>

Set or view the activity threshold for the `scan` command.

Usage: `scan threshold <n>`
- n: 0-100 (percentage). Default: 50

Examples:
  `scan threshold 30`   -> Set threshold to 30%
  `scan threshold`       -> Show current threshold

### 12. power \<1-4\>

Set the NRF24L01+ RF output power level. Sent to all slaves via I2C.

Usage: `power <1-4>`
- 1 = MIN (-18 dBm)
- 2 = LOW (-12 dBm)
- 3 = HIGH (-6 dBm)
- 4 = MAX (0 dBm, default)

Examples:
  `power`        -> Show current power
  `power 1`      -> Minimum power (shortest range)
  `power 4`      -> Maximum power (longest range)

### 13. adaptive

Adaptive jamming mode. Stops all jamming, scans all 13 Wi-Fi channels for 2 seconds, then assigns slaves to the busiest channels.

Usage: `adaptive`
- One-shot: scan, assign, jam, done

Usage: `adaptive start`
- Periodic mode: rescans and reassigns every N seconds (default 30s)

Usage: `adaptive stop`
- Stop periodic adaptive mode

Usage: `adaptive thresh <n>`
- Set minimum activity threshold (0-100%, default 0 = auto pick top 12)
- Channels below this threshold are skipped
- If no channels are above threshold, falls back to full spectrum

Usage: `adaptive intv <n>`
- Set rescan interval in seconds (5-300, default 30)

Example output:
```
Adaptive scanning...
..done
Targeting 3 busiest channels
Channels: 6 (71%), 7 (73%), 5 (48%)
```

Notes:
- Adaptive pauses all jamming before scanning (prevents self-interference)
- Cancelled by any mode-changing command (channel, set, start, stop, sweep)
- Fallback to full spectrum if no channels exceed threshold

### 14. sweep

Sweep mode — master cycles all slaves through Wi-Fi channels 1-13 at a configurable dwell time.

Usage: `sweep`
- Show current sweep status (active/inactive, current channel, dwell)

Usage: `sweep start`
- Start sweep mode from channel 1

Usage: `sweep stop`
- Stop sweep mode

Usage: `sweep <ms>`
- Set dwell time per channel (10-5000ms, default 200)

Notes:
- Uses fast `set_nrf_channel()` on slaves (~microseconds, not 100ms radio.init())
- Hardware switch position 3 enables hardware sweep mode
- Software sweep shares state with hardware sweep

### 15. pattern

Jamming burst pattern control. Pattern is sent to all slaves via I2C.

Usage: `pattern`
- Show current pattern type and timing

Usage: `pattern continuous`
- Default. Transmit continuously with no breaks.

Usage: `pattern pulsed <ms>`
- Alternating on/off periods of equal duration (5-5000ms).
- Master drives START/STOP cycles via I2C.
- Example: `pattern pulsed 100` -> 100ms jamming, 100ms silent

Usage: `pattern random`
- Random NRF frequency hop per packet (slave self-randomizes using LFSR).
- Frequency offset changes pseudo-randomly within the assigned channel.

Usage: `pattern burst <on_ms> <off_ms>`
- Custom on/off timing (5-5000ms each).
- Master drives START/STOP cycles via I2C.
- Example: `pattern burst 200 50` -> 200ms jamming, 50ms silent

### 16. profile save \<name\>

Save the current configuration (mode, channel, slave assignments) as a named profile in EEPROM.

Usage: `profile save <name>`
- name: up to 16 characters
- Max 16 profiles

### 17. profile load \<name\>

Load a previously saved profile.

Usage: `profile load <name>`
- Restores mode, channel, and slave slot configuration
- Does NOT automatically start jamming

### 18. profile list

List all saved profiles with their names and modes.

Example output:
```
Saved profiles:
 office  (ch6)
 outside (full)
 sweep_custom  (custom)
```

### 19. profile delete \<name\>

Delete a saved profile.

Usage: `profile delete <name>`

## MODES OVERVIEW

### SINGLE CHANNEL MODE (Fan-Out)

Slaves spread across the 22MHz channel width at 2MHz intervals.
Best for: Complete coverage of a single Wi-Fi channel

Usage: `channel <1-13>`
Example: `channel 6` -> Slaves spread 2426-2448 MHz (covering channel 6's full width)

Fan-out formula: `center_freq + (local_idx * 2) - (group_size - 1)`
- With 12 slaves (group_size=12): offsets -11 to +11 MHz from center
- local_idx 0: center - 11 MHz
- local_idx 11: center + 11 MHz

### FULL SPECTRUM MODE

Slaves spread across 60MHz span (2415-2470 MHz).
Best for: Wide coverage across multiple channels

Usage: `channel 0`
Frequency distribution:
  Slave 1: 2415 MHz
  Slave 2: 2420 MHz
  Slave 3: 2425 MHz
  ...
  Slave 12: 2470 MHz

### CUSTOM DISTRIBUTION MODE

Flexible assignment of slaves to specific channels.
Best for: Targeted jamming of specific channels

Usage: `set <distribution>`
Example: `set 4@1,2@6,2@11,4@6`
  -> 4 slaves on ch1, 2 on ch6, 2 on ch11, 4 on ch6
  -> Each channel group uses independent fan-out for full width coverage

**Local Index Fan-Out**: Each channel group is independently centered using
the formula: `center_freq + (local_idx * 2) - (group_size - 1)`

Example: `set 4@1,4@6,4@11`
  -> Each group has 4 slaves (group_size=4)
  -> Offsets within each group: -3, -1, +1, +3 MHz from channel center
  -> Channel 1 group: 2409, 2411, 2413, 2415 MHz
  -> Channel 6 group: 2434, 2436, 2438, 2440 MHz
  -> Channel 11 group: 2459, 2461, 2463, 2465 MHz

### SWEEP MODE

Cycles all 12 slaves through Wi-Fi channels 1-13 at configurable dwell time.
Best for: Systematic channel-by-channel jamming

Usage: `sweep start` / `sweep stop` / `sweep <ms>`
- Dwell default: 200ms per channel
- Full cycle (13 channels): 2.6s at default dwell

### ADAPTIVE MODE

Scans spectrum, identifies busiest channels, assigns slaves dynamically.
Best for: Reacting to changing RF environment

Usage: `adaptive` (one-shot) / `adaptive start` (periodic)
- 2-second scan of all 13 channels
- Assigns slaves to channels sorted by activity
- Threshold-based filtering available
- Fallback to full spectrum if no channels above threshold

### PATTERN MODES

Control the transmission pattern for jamming.

| Pattern | Usage | Timing Source |
|---|---|---|
| continuous | `pattern continuous` | N/A |
| pulsed | `pattern pulsed <ms>` | Master (I2C START/STOP) |
| random | `pattern random` | Slave (LFSR per packet) |
| burst | `pattern burst <on> <off>` | Master (I2C START/STOP) |

## HARDWARE SWITCH

The 3-position ON-OFF-ON switch provides hardware control:

| Position | Pin | Action |
|---|-----|---|
| 1 (ON) | D2 to GND | Full spectrum jamming |
| Center | Neither | Off (software control) |
| 3 (ON) | D3 to GND | Sweep mode |

Behavior:
- Switch overrides software commands for all modes
- D2 position takes priority over D3 (if both active, D2 = full spectrum)
- Moving to center stops jamming
- Software commands are blocked while switch is ON
- Serial messages confirm switch state changes

## USAGE EXAMPLES

### Example 1: Single Channel Jamming (with Fan-Out)
1. Connect to master via USB serial (115200 baud)
2. Type: `channel 6`
3. Type: `status`
4. Type: `start`
5. All 12 slaves spread across channel 6 (2426-2448 MHz)

### Example 2: Full Spectrum Coverage
1. Type: `channel 0`
2. Type: `status`
3. Type: `start`
4. Slaves spread across 2415-2470 MHz

### Example 3: Targeted Multi-Channel
1. Type: `set 4@1,4@6,4@11`
2. Type: `status`
3. Type: `start`
4. 4 slaves each on channels 1, 6, and 11

### Example 4: RF Site Survey
1. Type: `snapshot 10` — 10-second spectrum survey
2. Identify busiest channels from the bar graph
3. Type: `set 4@1,4@6,4@11` — assign slaves to busiest channels
4. Type: `start`

### Example 5: Adaptive Jamming
1. Type: `adaptive thresh 30`
2. Type: `adaptive start`
3. Master scans, assigns, and rescans every 30s
4. Type: `adaptive stop` to end

### Example 6: Sweep Mode
1. Type: `sweep 300` — 300ms per channel
2. Type: `sweep start`
3. Slaves cycle through channels 1-13
4. Type: `sweep stop` to end

### Example 7: Pattern Modes
1. Type: `channel 6`
2. Type: `pattern pulsed 100`
3. Type: `start`
4. Slaves alternate 100ms on/off on channel 6

### Example 8: Profile Presets
1. Setup a configuration: `set 4@1,4@6,4@11`
2. Save it: `profile save my_config`
3. Later load it: `profile load my_config`
4. Then: `start`

### Example 9: Stop and Restart
1. Type: `stop` (slaves idle, config retained)
2. Type: `channel 11` (change to channel 11)
3. Type: `start` (restart on new channel)

### Example 10: Custom Distribution
1. Type: `stop`
2. Type: `set 12@6`
3. Type: `start`
4. All 12 slaves on channel 6

### Example 11: Partial Deployment
1. Type: `set 6@1,6@6`
2. Type: `status`
3. Type: `start`
4. 6 slaves on ch1, 6 on ch6

## FREQUENCY TABLES

### Wi-Fi Channel Frequencies (Single Channel Mode with Fan-Out)
Channel | Center (MHz) | Fan-Out Range (MHz) | Notes
--------|--------------|---------------------|------------------
1       | 2412         | 2401-2423           | Common in US/EU
2       | 2417         | 2406-2428           |
3       | 2422         | 2411-2433           |
4       | 2427         | 2416-2438           |
5       | 2432         | 2421-2443           |
6       | 2437         | 2426-2448           | Non-overlapping with 1,11
7       | 2442         | 2431-2453           |
8       | 2447         | 2436-2458           |
9       | 2452         | 2441-2463           |
10      | 2457         | 2446-2468           |
11      | 2462         | 2451-2473           | Non-overlapping with 1,6
12      | 2467         | 2456-2478           |
13      | 2472         | 2461-2483           | EU only (US limit 11)

Fan-out formula: `center + (local_idx * 2) - (group_size - 1)` where local_idx is 0 to group_size-1
- Single channel mode: group_size=12, so offsets are -11 to +11 MHz

### Full Spectrum Mode Frequencies
Slave   | Frequency (MHz) | Channel Approx
--------|-----------------|------------------
1       | 2415            | Channel 1-2
2       | 2420            | Channel 2-3
3       | 2425            | Channel 3-4
4       | 2430            | Channel 4-5
5       | 2435            | Channel 5-6
6       | 2440            | Channel 6-7
7       | 2445            | Channel 7-8
8       | 2450            | Channel 8-9
9       | 2455            | Channel 9-10
10      | 2460            | Channel 10-11
11      | 2465            | Channel 11-12
12      | 2470            | Channel 12-13

## COMMAND SEQUENCE PATTERNS

### Pattern 1: Quick Setup
```
channel 6
start
status
```

### Pattern 2: Mode Switch
```
stop
channel 0
start
```

### Pattern 3: Custom Distribution
```
set 4@1,4@6,4@11
status
start
```

### Pattern 4: Pause and Resume
```
stop
(status check)
start
```

### Pattern 5: Full Reset
```
stop
channel 0
start
```

### Pattern 6: Site Survey + Adaptive
```
snapshot 10
adaptive thresh 30
adaptive start
```

### Pattern 7: Sweep
```
sweep 250
sweep start
sweep stop
```

### Pattern 8: Profile Workflow
```
set 6@1,6@6
profile save balanced
stop
channel 0
profile save full_spectrum
profile load balanced
start
```

### Pattern 9: Pulsed Pattern
```
channel 6
pattern pulsed 200
start
```

## TROUBLESHOOTING

Issue: "Slave Not Found"
Solution:
- Check I2C wiring (`SDA=A4`, `SCL=A5`)
- Verify slave address (`0x01`-`0x0C`)
- Ensure common ground
- Check NRF24L01+ VCC (3.3V critical)

Issue: "Active: X/12" (fewer than 12)
Solution:
- Verify all slaves powered
- Check I2C connections on all nodes
- Verify `SLAVE_ID` set correctly (0-11)
- Ensure no duplicate addresses

Issue: Frequency Drift
Solution:
- Check stable 3.3V supply
- Add 10uF + 0.1uF capacitors near VCC/GND
- Minimize power supply distance

Issue: Config Not Persisting
Solution:
- Use `stop` before power cycle
- Configuration only resets on physical restart
- Check `current_mode` variable not overwritten

Issue: Slaves not transmitting
Solution:
- Verify `start` command issued
- Check mode and channel set correctly
- Verify NRF24L01+ CE pin (Pin 9) connected
- Check antenna attached

Issue: NRF24L01+ RX Module Not Detected
Solution:
- Check wiring: CE=D9, CSN=D10, MOSI=D11, MISO=D12, SCK=D13
- VCC must be 3.3V (NOT 5V)
- Verify common ground between Nano and NRF module

Issue: Can't Send Software Commands
Solution:
- Check if hardware switch is ON (position 1 or 3)
- Move switch to center position for software control
- Switch overrides all software commands

## QUICK REFERENCE CARD

Command                 | Syntax                     | Effect
------------------------|----------------------------|------------------
help                    | help                       | Show commands
get                     | get or get 0,1,2           | Query slaves
set                     | set 4@1,2@6,2@11           | Custom dist
channel                 | channel 0-13               | Set mode
start                   | start                      | Begin TX
stop                    | stop                       | Halt TX
status                  | status                     | Show distribution & health
snapshot                | snapshot or snapshot 30    | RF spectrum snapshot
scan                    | scan                       | Threshold scan all ch
scan <ch>               | scan 6 30                  | Live waterfall
scan threshold          | scan threshold 50          | Set threshold %
power                   | power 1-4                  | Set TX power
adaptive                | adaptive                   | One-shot adaptive
adaptive start          | adaptive start             | Periodic adaptive
adaptive stop           | adaptive stop              | Stop adaptive
adaptive thresh         | adaptive thresh 30         | Adaptive min %
adaptive intv           | adaptive intv 60           | Rescan interval
sweep                   | sweep                      | Show sweep status
sweep start             | sweep start                | Start sweep
sweep stop              | sweep stop                 | Stop sweep
sweep <ms>              | sweep 300                  | Set dwell
pattern                 | pattern                    | Show pattern
pattern continuous      | pattern continuous         | Continuous TX
pattern pulsed          | pattern pulsed 100         | Pulsed on/off
pattern random          | pattern random             | Freq hop per packet
pattern burst           | pattern burst 200 50       | Custom on/off
profile save            | profile save my_cfg        | Save profile
profile load            | profile load my_cfg        | Load profile
profile list            | profile list               | List profiles
profile delete          | profile delete my_cfg      | Delete profile

### Mode Values
0 = N/A (used by channel 0)
1 = Single Channel (fan-out across 22MHz channel width at 2MHz intervals)
2 = Full Spectrum (spread 60MHz at 5MHz intervals)
3 = Custom Distribution (flexible, uses fan-out within each channel)
4 = Sweep (cycling through channels)

### Power Levels
Value | Command | NRF Register | Output Power
------|---------|-------------|-------------
1 | power 1 | 0 (RF24_PA_MIN) | -18 dBm
2 | power 2 | 1 (RF24_PA_LOW) | -12 dBm
3 | power 3 | 2 (RF24_PA_HIGH) | -6 dBm
4 | power 4 | 3 (RF24_PA_MAX) | 0 dBm

## NOTES

- All commands case-insensitive
- Configuration persists after `stop`
- Physical restart required to clear config
- Slaves numbered 1-12 in output (internal: 0-11)
- Max frequency: 2527 MHz (NRF24L01+ limit)
- Min frequency: 2400 MHz (NRF24L01+ limit)
- Power requirement: 1A+ supply for 13 nodes
- Hardware switch ON-OFF-ON on D2/D3 (active LOW, internal pull-up)
  - Pos 1 (D2=GND): Full spectrum jamming (takes priority)
  - Center: Off (software control)
  - Pos 3 (D3=GND): Sweep mode
- Adaptive mode pauses TX during scan to avoid self-interference
- Random pattern uses slave LFSR for per-packet frequency offset
- Profile EEPROM: up to 16 profiles, auto-initialized on first use
- Threshold-based scan only shows channels above `scan threshold %`
- Sweep uses per-channel dwell timing on master, direct RF_CH write on slave (~µs)
- I2C protocol: 6 bytes (mode, channel, cmd, packed fanout, power, pattern_type)

---

**Version**: 2.0
**Last Updated**: May 2026
**Author**: Ryon Sherman

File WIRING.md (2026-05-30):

# Arduino Wi-Fi Jammer - Wiring Diagram (ASCII)

## System Overview

```
                          MASTER NODE
                   (Arduino Nano + NRF24L01+)
                       I2C Address: 0x70
                        NRF24 Mode: RX

          USB ---> Serial Monitor (115200 baud)

          SDA ---+----------------------------+
          SCL ---+----------------------------+
          VCC ---+----------------------------+
          GND ---+----------------------------+
                 |                            |
                 |          I2C BUS           |
                 |     (SDA/SCL parallel)     |
                 |                            |
 +-----------+---+-----------+---+------------+---+------------+
 |  SLAVE #0 |   |  SLAVE #1 |   |  SLAVE #X  |   |  SLAVE #11 |
 |  0x01     |   |  0x02     |   |  ...       |   |  0x0C      |
 +-----------+   +-----------+   +------------+   +------------+
```

## Master Node (0x70)

```
+----------------------------------------------+
|              ARDUINO NANO                    |
|                                              |
|   +---------------------------------------+  |
|   |           NRF24L01+ MODULE            |  |
|   |                                       |  |  
|   |   VCC  ----+--------------------------+  |
|   |            | (3.3V critical!)         |  |
|   |   GND  ----+--------------------------+  |
|   |   CE   ----+------- Pin 9             |  |
|   |   CSN  ----+------- Pin 10            |  |
|   |   SCK  ----+------- Pin 13 (SPI SCK)  |  |
|   |   MISO ----+------- Pin 12 (SPI MISO) |  |
|   |   MOSI ----+------- Pin 11 (SPI MOSI) |  |
|   |   IRQ  ----+------- (optional)        |  |
|   +---------------------------------------+  |
|                                              |
|   I2C Connections:                           | 
|   SDA  ------------------------ Pin A4       | 
|   SCL  ------------------------ Pin A5       |
|                                              |
|   USB Serial:                                |
|   TX   ------------------------ USB TX       |
|   RX   ------------------------ USB RX       |
|   GND  ------------------------ USB GND      |
+----------------------------------------------+
```

## Slave Nodes (0x01-0x0C)

The slaves use MH-Tiny ATtiny88 clones (TQFP-32) with ATTinyCore board package.
Pin numbers below are Arduino-logical (mapped by ATTinyCore).

```
+----------------------------------------------+
|            MH-TINY (ATTINY88)                |
|                                              |
|   +-------------------------------------+    |
|   |           NRF24L01+ MODULE          |    |
|   |                                     |    |
|   |   VCC  ----+------------------------+    |
|   |            | (3.3V critical!)       |    |
|   |   GND  ----+------------------------+    |
|   |   CE   ----+------- Pin 9  (PB1)    |    |
|   |   CSN  ----+------- Pin 10 (PB2)    |    |
|   |   SCK  ----+------- Pin 13 (PB5)    |    |
|   |   MISO ----+------- Pin 12 (PB4)    |    |
|   |   MOSI ----+------- Pin 11 (PB3)    |    |
|   |   IRQ  ----+------- (optional)      |    |
|   +-------------------------------------+    |
|                                              |
|   I2C Connections:                           |
|   SDA  ------------------------ Pin 23 (PC4) |
|   SCL  ------------------------ Pin 24 (PC5) |
|                                              |
|   Configuration:                             |
|   #define SLAVE_ID X (X = 0-11)              |
|   I2C Address = 0x01 + SLAVE_ID              |
+----------------------------------------------+
```

## I2C Bus Topology

```
                  MASTER (0x70)
                        |
   +--------------------+------------------+
   |                    |                  |
+--+--------+  +--------+----+  +----------+--+
| MH-TINY   |  |  MH-TINY    |  |  MH-TINY    |
| SLAVE #0  |  |  SLAVE #1   |  |  SLAVE #11  |
| 0x01      |  |  0x02       |  |  0x0C       |
+-----------+  +-------------+  +-------------+

All nodes share the same SDA and SCL lines (parallel bus)
```

## Wiring Table

| Connection | Master (Nano) | Slaves (MH-Tiny) |
|---|---|---|
| SDA | A4 | Pin 23 (PC4) |
| SCL | A5 | Pin 24 (PC5) |
| VCC | 3.3V | 3.3V |
| GND | GND | GND |
| CE | Pin 9 | Pin 9  (PB1) |
| CSN | Pin 10 | Pin 10 (PB2) |
| SCK | Pin 13 | Pin 13 (PB5) |
| MOSI | Pin 11 | Pin 11 (PB3) |
| MISO | Pin 12 | Pin 12 (PB4) |

## NRF24L01+ Module Pinout

```
+--------------------------------------------+
|          NRF24L01+ MODULE                  |
|                                            |
|   VCC   ----+                              |
|             | (3.3V DC)                    |
|   GND   ----+-------------------+          |
|   CE    ----+-------------------+ Pin 9    |
|   CSN   ----+-------------------+ Pin 10   |
|   SCK   ----+-------------------+ Pin 13   |
|   MOSI  ----+-------------------+ Pin 11   |
|   MISO  ----+-------------------+ Pin 12   |
|   IRQ   ----+ (optional, unused)           |
|                                            |
|   Antenna --+----------------------------- +
|                                            |
|   Notes:                                   |
|   - VCC MUST be 3.3V (not 5V!)             |
|   - Add capacitor 10uF + 0.1uF near VCC    |
|   - Keep antenna away from digital lines   |
+--------------------------------------------+
```

## NRF24L01+ Decoupling Capacitors

Place a 10uF + 0.1uF capacitor pair as close as possible to each NRF24L01+ module's VCC/GND pins.

```
         NRF24L01+ MODULE
    +-----------------------+
    |                       |
    |  VCC o--+------+------+--- 3.3V rail
    |          |      |
    |         +-+    +-+
    |         | |    | | 10uF (electrolytic / tantalum)
    |         | |    | |  (+ side to VCC)
    |         +-+    +-+
    |          |      |
    |         +-+    +-+
    |         | |    | | 0.1uF (ceramic)
    |         | |    | |
    |         +-+    +-+
    |          |      |
    |  GND o--+------+------+--- GND rail
    |                       |
    +-----------------------+

    Notes:
    - Both caps connect directly between VCC and GND (parallel)
    - 10uF = bulk decoupling (handles sudden current draws during TX)
    - 0.1uF = high-frequency noise suppression
    - Place capacitors as close to module pins as possible
    - Keep leads short — long wires reduce effectiveness
```

## Power Distribution

For battery-powered operation, use a 9V battery → buck converter → 5V rail → 100uF bulk cap.

```
    +-----+         +-------------------+         +-----------+
    | 9V  |         |   Buck Converter  |         |  100uF    |
    | Bat |---------|  (step-down)      |---------| Electrolyt|----- 5V rail
    |     | 9V in   |  5V out, 3A max   |  5V out |  (+ to 5V)| 
    +-----+         +-------------------+         +-----------+     
                                                        |
                                                       === GND

                               5V RAIL
    +------------------+------------------+------------------+
    |                  |                  |                  |
 +--+--------+    +----+-------+    +-----+-------+    +----+------+
 |  Master   |    |  Slave #0  |    |  Slave #1   |    | Slave #11 |
 |  Arduino  |    | MH-Tiny    |    |  MH-Tiny    |    | MH-Tiny   |
 |  Nano     |    | + NRF24    |    |  + NRF24    |    | + NRF24   |
 |  5V pin   |    | 5V input   |    |  5V input   |    | 5V input  |
 +-----------+    +------------+    +-------------+    +-----------+
    |                  |                  |                  |
    +------------------+------------------+------------------+
                     GND RAIL (common ground)

    Notes:
    - Buck converter: adjust output to 5V before connecting
    - 100uF cap: bulk decoupling at the power entry point
    - Each NRF24 module also needs its own 10uF + 0.1uF near VCC
    - 1A+ supply recommended for all 13 nodes
    - Keep power wires short and use thick gauge for the 5V rail
```

## Current Requirements

| Node Type | Max Current | Typical Current |
|---|---|---|
| Arduino Nano (master)| 50mA | 20mA |
| MH-Tiny ATtiny88 | 10mA | 5mA |
| NRF24L01+ TX mode | 11.5mA | 10mA |
| NRF24L01+ RX mode | 14.5mA | 12mA |
| **Total per Slave**  | ~62mA | ~32mA |
| **Total System** | ~806mA | ~416mA |

    Recommendation: 1A+ power supply for all 13 nodes

## Connection Checklist

Pre-Flight Wiring Check:
- [ ] All nodes share common GND
- [ ] NRF24L01+ VCC: 3.3V (direct to module) or 5V (if breakout has regulator)
- [ ] SDA connected on all nodes (Nano A4, MH-Tiny Pin 23)
- [ ] SCL connected on all nodes (Nano A5, MH-Tiny Pin 24)
- [ ] CE pin (9) connected on all nodes
- [ ] CSN pin (10) connected on all nodes
- [ ] SPI pins (11, 12, 13) connected on all nodes
- [ ] Antenna attached to all NRF24L01+ modules
- [ ] Master connected to USB serial
- [ ] Power source capable of 1A+

## I2C Address Verification

| Node Type  | SLAVE_ID | I2C Address |
|---|---|---|
| Master | N/A | 0x70 |
| Slave 0 | 0 | 0x01 |
| Slave 1 | 1 | 0x02 |
| ... | ... | ... |
| Slave 11 | 11 | 0x0C |

## Troubleshooting Wiring Issues

No ACK on I2C:
- Check common ground connection
- Verify SDA/SCL pull-up resistors (4.7k ohm recommended)
- Ensure VCC is stable (voltage drops affect I2C)

NRF24L01+ Not Found:
- Verify VCC is 3.3V (critical!)
- Check CE pin connection (Pin 9)
- Check CSN pin connection (Pin 10)
- Ensure SPI bus is intact (MOSI, MISO, SCK)

Slave Count < 12:
- Check unique SLAVE_ID (0-11) in each slave code
- Verify I2C address not duplicated
- Check for wiring shorts on SDA/SCL lines

Frequency Drift:
- Ensure stable 3.3V supply to NRF24L01+
- Add 10uF + 0.1uF capacitors near VCC/GND
- Minimize distance between power source and nodes

---

**Version**: 1.0  
**Last Updated**: May 2026  
**Author**: Ryon Sherman

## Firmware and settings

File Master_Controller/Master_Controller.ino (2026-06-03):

/**
 * Master_Controller.ino
 * 
 * Master node for distributed Wi-Fi jamming. Runs on Arduino Nano.
 * Handshakes with 12 slave units via I2C (address 0x70),
 * sends channel/mode commands, reports status over USB Serial.
 * 
 * Hardware switch on D2 enables full-spectrum jamming when ON.
 * 
 * Memory: ATmega328P has 2KB RAM, ~1.5KB used by this code + Serial buffer
 */

#include <Wire.h>
#include <SPI.h>
#include <EEPROM.h>

// --- Configuration ---
#define MASTER_ADDR 0x70
#define TOTAL_SLAVES 12

// --- Hardware Switch ---
#define HW_SWITCH_PIN 2  // D2 - connect switch between D2 and GND
#define HW_SWEEP_PIN 3   // D3 - sweep mode (position 3 of ON-OFF-ON)

// --- NRF24L01+ RX Scanner ---
#define NRF_CE_PIN 9
#define NRF_CSN_PIN 10

static uint8_t nrf_read_reg(uint8_t reg) {
  digitalWrite(NRF_CSN_PIN, LOW);
  SPI.transfer(reg);
  uint8_t val = SPI.transfer(0x00);
  digitalWrite(NRF_CSN_PIN, HIGH);
  return val;
}

static void nrf_write_reg(uint8_t reg, uint8_t val) {
  digitalWrite(NRF_CSN_PIN, LOW);
  SPI.transfer(0x20 | reg);
  SPI.transfer(val);
  digitalWrite(NRF_CSN_PIN, HIGH);
}

// Compile-time guard: local_idx and group_size are packed into 4-bit nibbles (max 15)
// See send_cmd() byte 4 packing and Slave_Transmitter.ino FANOUT_* macros
#if TOTAL_SLAVES > 15
#error "TOTAL_SLAVES exceeds 15 - nibble packing in send_cmd() byte 4 will overflow"
#endif
#define SLAVE_ADDR_START 0x01

// --- Modes ---
#define MODE_SINGLE_CHANNEL 1
#define MODE_FULL_SPECTRUM 2
#define MODE_CUSTOM 3
#define MODE_SWEEP 4

// --- Commands ---
#define CMD_START 1
#define CMD_STOP 0

// --- Status Polling ---
#define STATUS_INTERVAL_MS 5000

// --- State (optimized layout) ---
static uint8_t slave_count = 0;
static uint8_t selected_channel = 0;
static uint8_t current_mode = MODE_FULL_SPECTRUM;
static bool jamming_active = false;
static bool hw_jamming_active = false;  // Hardware switch state
static uint32_t last_status_ms = 0;
static uint8_t current_power = 3;  // 0=MIN, 1=LOW, 2=HIGH, 3=MAX (default)

// Slave health cache (populated by poll_slaves)
static bool slave_online[TOTAL_SLAVES];
static uint8_t slave_rtt_us[TOTAL_SLAVES];

// Adaptive jamming state
static bool adaptive_active = false;
static uint16_t adaptive_interval_sec = 30;
static uint8_t adaptive_threshold = 0;
static uint32_t last_adaptive_ms = 0;

// Sweep mode state
static bool hw_sweep_active = false;   // D3 LOW = sweep via HW switch
static bool sweep_active = false;      // sweep via software command
static uint8_t sweep_channel = 1;      // current sweep position
static uint16_t sweep_dwell_ms = 200;  // ms per channel
static uint32_t last_sweep_ms = 0;

// Burst pattern state
static uint8_t current_pattern = 0;    // 0=continuous, 1=pulsed, 2=random, 3=burst
static uint16_t pattern_on_ms = 50;    // on time (ms)
static uint16_t pattern_off_ms = 50;   // off time (ms)
static bool pattern_state = true;      // true=on, false=off
static uint32_t pattern_timer = 0;

// Scan threshold
static uint8_t scan_threshold = 50;  // default 50%

// Packed slave config: 4 bytes per slave instead of 4 (struct padding eliminated)
// Layout: [channel:4bits][active:1bit][unused:3bits] = 1 byte per slave
static uint8_t slave_cfg[TOTAL_SLAVES];  // Was 48 bytes (struct), now 12 bytes

// Bounds-checked config access macros (WARN-2 fix)
#define CFG_GET_CHANNEL(i)  ((i) < TOTAL_SLAVES ? (slave_cfg[i] >> 4) : 0)
#define CFG_GET_ACTIVE(i)   ((i) < TOTAL_SLAVES ? (slave_cfg[i] & 0x01) : 0)

// Profile presets (stored in EEPROM)
#define PROFILE_MAGIC      0x4A
#define OFFSET_PROF_COUNT  1
#define OFFSET_PROFILES    2
#define PROFILE_NAME_LEN   16
#define PROFILE_SIZE       (1 + 1 + TOTAL_SLAVES + PROFILE_NAME_LEN)  // mode, channel, cfg, name

static uint16_t profile_offset(uint8_t idx) {
  return OFFSET_PROFILES + idx * PROFILE_SIZE;
}
static void profile_init(void) {
  if (EEPROM.read(0) != PROFILE_MAGIC) { EEPROM.write(0, PROFILE_MAGIC); EEPROM.write(OFFSET_PROF_COUNT, 0); }
}
static uint8_t profile_count(void) { return EEPROM.read(OFFSET_PROF_COUNT); }
#define CFG_SET(i, ch, act) do { if ((i) < TOTAL_SLAVES) slave_cfg[i] = (((ch) & 0x0F) << 4) | ((act) ? 1 : 0); } while(0)

// ── Profile Presets (EEPROM-backed) ──────────────────────────────
static void trim_str(char* s) {
  char* p = s;
  while (*p == ' ') p++;
  if (p != s) { memmove(s, p, strlen(p) + 1); }
  for (int i = strlen(s) - 1; i >= 0 && s[i] == ' '; i--) s[i] = 0;
}
static bool profile_write(uint8_t idx, const char* name) {
  uint16_t off = profile_offset(idx);
  EEPROM.write(off++, current_mode);
  EEPROM.write(off++, selected_channel);
  for (uint8_t i = 0; i < TOTAL_SLAVES; i++) EEPROM.write(off++, slave_cfg[i]);
  for (uint8_t i = 0; i < PROFILE_NAME_LEN; i++) EEPROM.write(off++, name[i] ? name[i] : 0);
  return true;
}
static bool profile_name_match(uint8_t idx, const char* name) {
  uint16_t off = profile_offset(idx) + 2 + TOTAL_SLAVES;
  for (uint8_t i = 0; i < PROFILE_NAME_LEN; i++) {
    uint8_t c = EEPROM.read(off++);
    if (c != (uint8_t)name[i]) return false;
    if (c == 0 && name[i] == 0) return true;
  }
  return true;
}
static void profile_load(uint8_t idx) {
  uint16_t off = profile_offset(idx);
  current_mode = EEPROM.read(off++);
  selected_channel = EEPROM.read(off++);
  for (uint8_t i = 0; i < TOTAL_SLAVES; i++) slave_cfg[i] = EEPROM.read(off++);
}
static uint8_t find_profile(const char* name) {
  uint8_t cnt = profile_count();
  for (uint8_t i = 0; i < cnt; i++) if (profile_name_match(i, name)) return i;
  return 255;
}
static bool profile_save(const char* name) {
  profile_init();
  uint8_t cnt = profile_count();
  for (uint8_t i = 0; i < cnt; i++) { if (profile_name_match(i, name)) { profile_write(i, name); return true; } }
  if (cnt >= 16) return false;
  profile_write(cnt, name);
  EEPROM.write(OFFSET_PROF_COUNT, cnt + 1);
  return true;
}
static bool profile_delete_at(uint8_t idx) {
  uint8_t cnt = profile_count();
  if (idx >= cnt) return false;
  for (uint8_t i = idx; i < cnt - 1; i++) {
    uint16_t src = profile_offset(i + 1);
    uint16_t dst = profile_offset(i);
    for (uint8_t b = 0; b < PROFILE_SIZE; b++) EEPROM.write(dst++, EEPROM.read(src++));
  }
  EEPROM.write(OFFSET_PROF_COUNT, cnt - 1);
  return true;
}
static void cmd_profile(const char* rest) {
  char name[PROFILE_NAME_LEN];
  if (!rest || rest[0] == 0) { profile_list(); return; }
  if (strncmp_P(rest, PSTR("save "), 5) == 0) {
    if (rest[5] == 0) { Serial.println(F("Usage: profile save <name>")); return; }
    strncpy(name, rest + 5, PROFILE_NAME_LEN - 1); name[PROFILE_NAME_LEN - 1] = 0;
    trim_str(name);
    if (name[0] == 0) { Serial.println(F("Invalid name")); return; }
    if (profile_save(name)) { Serial.print(F("Profile '")); Serial.print(name); Serial.println(F("' saved")); }
    else { Serial.println(F("Max 16 profiles")); }
  } else if (strncmp_P(rest, PSTR("load "), 5) == 0) {
    if (rest[5] == 0) { Serial.println(F("Usage: profile load <name>")); return; }
    strncpy(name, rest + 5, PROFILE_NAME_LEN - 1); name[PROFILE_NAME_LEN - 1] = 0;
    trim_str(name);
    uint8_t idx = find_profile(name);
    if (idx == 255) { Serial.print(F("Profile '")); Serial.print(name); Serial.println(F("' not found")); return; }
    profile_load(idx);
    Serial.print(F("Profile '")); Serial.print(name); Serial.println(F("' loaded"));
  } else if (strncmp_P(rest, PSTR("delete "), 7) == 0) {
    if (rest[7] == 0) { Serial.println(F("Usage: profile delete <name>")); return; }
    strncpy(name, rest + 7, PROFILE_NAME_LEN - 1); name[PROFILE_NAME_LEN - 1] = 0;
    trim_str(name);
    uint8_t idx = find_profile(name);
    if (idx == 255) { Serial.print(F("Profile '")); Serial.print(name); Serial.println(F("' not found")); return; }
    profile_delete_at(idx);
    Serial.print(F("Profile '")); Serial.print(name); Serial.println(F("' deleted"));
  } else if (strcmp_P(rest, PSTR("list")) == 0) {
    profile_list();
  } else {
    Serial.println(F("profile [save|load|delete|list]"));
  }
}
static void profile_list(void) {
  profile_init();
  uint8_t cnt = profile_count();
  if (cnt == 0) { Serial.println(F("No saved profiles")); return; }
  Serial.println(F("Saved profiles:"));
  for (uint8_t i = 0; i < cnt; i++) {
    uint16_t off = profile_offset(i);
    uint8_t mode = EEPROM.read(off++);
    uint8_t ch = EEPROM.read(off++);
    Serial.write(' ');
    for (uint8_t j = 0; j < PROFILE_NAME_LEN; j++) {
      uint8_t c = EEPROM.read(off + TOTAL_SLAVES + j);
      if (c == 0) break;
      Serial.write(c);
    }
    Serial.print(F("  ("));
    if (mode == MODE_SINGLE_CHANNEL) { Serial.print(F("ch")); Serial.print(ch); }
    else if (mode == MODE_FULL_SPECTRUM) { Serial.print(F("full")); }
    else { Serial.print(F("custom")); }
    Serial.println(')');
  }
}

/**
 * Send I2C command to a specific slave
 * Byte 4 packs local_idx (high nibble) + group_size (low nibble) for fan-out
 * Byte 5: power level (0=MIN, 1=LOW, 2=HIGH, 3=MAX)
 * Byte 6: pattern_type (0=continuous, 1=pulsed, 2=random, 3=burst)
 */
static void send_cmd(uint8_t slave_id, uint8_t mode, uint8_t channel, uint8_t cmd, uint8_t local_idx, uint8_t group_size) {
  Wire.beginTransmission(SLAVE_ADDR_START + slave_id);
  Wire.write(mode);
  Wire.write(channel);
  Wire.write(cmd);
  Wire.write(((local_idx & 0x0F) << 4) | (group_size & 0x0F));
  Wire.write(current_power);
  Wire.write(current_pattern);
  Wire.endTransmission();
}

/**
 * Send I2C command to all slaves (single channel or full spectrum mode)
 */
static void send_cmd_all(uint8_t mode, uint8_t channel, uint8_t cmd) {
  for (uint8_t i = 0; i < TOTAL_SLAVES; i++) {
    send_cmd(i, mode, channel, cmd, i, TOTAL_SLAVES);
  }
}

/**
 * Send custom commands to each slave based on their config
 * Uses local indexing within each channel group for balanced fan-out
 * 
 * One-pass algorithm: iterate by channel, then by slave.
 * For each channel, first count active slaves (group_size), then send
 * commands to each with incrementing local_idx. Only 2 bytes stack usage.
 * 
 * NOTE: This channel-grouping logic must stay in sync with print_freq_map().
 * Both functions compute (group_size, local_idx) per channel but use different
 * algorithms optimized for their use case:
 * - send_custom_cmds(): one-pass, sends immediately (no array storage)
 * - print_freq_map(): two-pass with arrays (channels must print in slave order)
 * If you modify the grouping logic here, update print_freq_map() to match.
 */
static void send_custom_cmds(uint8_t cmd) {
  for (uint8_t ch = 1; ch <= 13; ch++) {
    // Count slaves on this channel
    uint8_t group_size = 0;
    for (uint8_t i = 0; i < TOTAL_SLAVES; i++) {
      if (CFG_GET_ACTIVE(i) && CFG_GET_CHANNEL(i) == ch) {
        group_size++;
      }
    }
    if (group_size == 0) continue;
    
    // Send commands with local index
    uint8_t local_idx = 0;
    for (uint8_t i = 0; i < TOTAL_SLAVES; i++) {
      if (CFG_GET_ACTIVE(i) && CFG_GET_CHANNEL(i) == ch) {
        send_cmd(i, MODE_CUSTOM, ch, cmd, local_idx++, group_size);
      }
    }
  }
}

/**
 * Scan all slaves via I2C handshake
 * @return: Number of responsive slaves (0-12)
 */
static uint8_t scan_slaves() {
  uint8_t count = 0;
  
  Serial.println(F("\n=== Scanning Slaves ==="));
  
  for (uint8_t i = 0; i < TOTAL_SLAVES; i++) {
    Wire.beginTransmission(SLAVE_ADDR_START + i);
    uint8_t status = Wire.endTransmission();
    
    Serial.print(status == 0 ? F("[OK] ") : F("[--] "));
    Serial.print(F("Slave "));
    Serial.println(i);
    
    if (status == 0) count++;
  }
  
  return count;
}

/**
 * Calculate frequency offset for display
 * Uses local fan-out formula: center + (local_idx * 2) - (group_size - 1)
 */
static uint8_t calc_freq(uint8_t local_idx, uint8_t group_size, uint8_t mode, uint8_t channel) {
  if (mode == MODE_SINGLE_CHANNEL || mode == MODE_CUSTOM || mode == MODE_SWEEP) {
    // center = 12 + (ch-1)*5 = 7 + ch*5
    // offset = (local_idx * 2) - (group_size - 1)
    // freq = center + offset = 7 + ch*5 + local_idx*2 - group_size + 1 = 8 + ch*5 + local_idx*2 - group_size
    int8_t offset = (local_idx << 1) - (group_size - 1);
    uint8_t center = 7 + (channel << 2) + channel;  // 7 + ch*5
    return center + offset;
  }
  // Full spectrum: 14 + local_idx*5  (staggered between channels for max coverage)
  return 14 + (local_idx << 2) + local_idx;
}

/**
 * Check if NRF24L01+ is responding by verifying register read/write
 * Returns true if module responds correctly
 */
static bool nrf_check() {
  pinMode(NRF_CE_PIN, OUTPUT);
  pinMode(NRF_CSN_PIN, OUTPUT);
  digitalWrite(NRF_CE_PIN, LOW);
  digitalWrite(NRF_CSN_PIN, HIGH);
  SPI.begin();
  SPI.beginTransaction(SPISettings(8000000, MSBFIRST, SPI_MODE0));
  
  // Test 1: Read CONFIG register - should have sane default (0x08 after reset)
  uint8_t cfg = nrf_read_reg(0x00);
  if (cfg == 0xFF || cfg == 0x00) {
    // 0xFF = no device (MISO pulled high), 0x00 = stuck low
    SPI.endTransaction();
    SPI.end();
    return false;
  }
  
  // Test 2: Write/read RF_CH register with test value
  uint8_t test_ch = 0x4C;  // 76 decimal - arbitrary test value
  nrf_write_reg(0x05, test_ch);
  delayMicroseconds(10);
  uint8_t readback = nrf_read_reg(0x05);
  
  // Reset RF_CH to 0 before returning
  nrf_write_reg(0x05, 0x00);
  
  SPI.endTransaction();
  SPI.end();
  
  return (readback == test_ch);
}

/**
 * Initialize NRF24L01+ in RX scan mode using direct register access
 */
static bool nrf_scan_init() {
  pinMode(NRF_CE_PIN, OUTPUT);
  pinMode(NRF_CSN_PIN, OUTPUT);
  digitalWrite(NRF_CE_PIN, LOW);
  digitalWrite(NRF_CSN_PIN, HIGH);
  SPI.begin();
  SPI.beginTransaction(SPISettings(8000000, MSBFIRST, SPI_MODE0));

  nrf_write_reg(0x00, 0x0B);  // CONFIG: PWR_UP=1, PRIM_RX=1, CRC=0
  delay(5);
  return true;
}

/**
 * Scan a single NRF channel for carrier detect (RPD)
 * Returns 1 if signal > ~-64 dBm detected
 */
static uint8_t nrf_scan_channel(uint8_t ch) {
  digitalWrite(NRF_CE_PIN, LOW);
  delayMicroseconds(4);
  nrf_write_reg(0x05, ch);
  delayMicroseconds(4);
  digitalWrite(NRF_CE_PIN, HIGH);
  delayMicroseconds(130);
  return nrf_read_reg(0x09) & 0x01;
}

/**
 * Single RF spectrum snapshot
 * Collects data for 5 seconds, then displays aggregated results
 */
static void cmd_snapshot(uint8_t seconds) {
  if (!nrf_scan_init()) return;

  Serial.println(F("\n======= RF Snapshot ======="));
  Serial.print(F("Collecting data"));

  uint16_t counts[14] = {0};  // channels 1-13
  uint16_t passes = 0;
  uint32_t start = millis();
  uint32_t duration = (uint32_t)seconds * 1000;
  uint8_t last_dot = 0;

  while (millis() - start < duration) {
    for (uint8_t ch = 1; ch <= 13; ch++) {
      uint8_t nrf_center = 7 + ch * 5;
      if (nrf_scan_channel(nrf_center)) counts[ch]++;
    }
    passes++;
    
    // Print dot every 3 seconds
    uint8_t elapsed_dots = (millis() - start) / 3000;
    if (elapsed_dots > last_dot) {
      Serial.print('.');
      last_dot = elapsed_dots;
    }
  }

  digitalWrite(NRF_CE_PIN, LOW);
  SPI.endTransaction();
  SPI.end();

  Serial.println(F(" done"));
  Serial.println(F("---------------------------"));
  Serial.println(F("Ch  Freq        Signal"));
  for (uint8_t ch = 1; ch <= 13; ch++) {
    uint8_t pct = (uint32_t)counts[ch] * 100 / passes;

    if (ch < 10) Serial.print(' ');
    Serial.print(ch);
    Serial.print(F("  "));
    Serial.print(2400 + 7 + ch * 5);
    Serial.print(F(" MHz "));

    for (uint8_t i = 0; i < 10; i++) {
      Serial.print(i * 10 < pct ? '#' : '.');
    }
    Serial.print(F(" "));
    if (pct < 10) Serial.print(' ');
    Serial.print(pct);
    Serial.println('%');
  }
  
  Serial.println(F("==========================="));
}

/**
 * Continuous RF waterfall scan for a single Wi-Fi channel
 * Shows signal intensity over time with a bar graph per second
 */
static void cmd_scan_channel(uint8_t wifi_ch, uint8_t seconds) {
  if (!nrf_scan_init()) return;

  uint8_t nrf_center = 7 + wifi_ch * 5;
  uint16_t freq = 2400 + nrf_center;

  Serial.println(F("\n======== RF Live Scan ========"));
  Serial.print(F("Channel "));
  Serial.print(wifi_ch);
  Serial.print(F(" ("));
  Serial.print(freq);
  Serial.print(F(" MHz) for "));
  Serial.print(seconds);
  Serial.println(F("s"));
  Serial.println(F("------------------------------"));

  uint32_t start = millis();
  uint8_t last_sec = 255;
  uint16_t hits = 0;
  uint16_t samples = 0;

  while (millis() - start < (uint32_t)seconds * 1000) {
    uint8_t cur_sec = (millis() - start) / 1000;
    
    if (nrf_scan_channel(nrf_center)) hits++;
    samples++;
    
    // Print once per second
    if (cur_sec != last_sec && last_sec != 255) {
      uint8_t pct = samples > 0 ? (uint32_t)hits * 100 / samples : 0;
      
      // 20-char bar
      for (uint8_t i = 0; i < 20; i++) {
        Serial.print(i * 5 < pct ? '#' : '.');
      }
      Serial.print(F(" "));
      if (pct < 10) Serial.print(' ');
      if (pct < 100) Serial.print(' ');
      Serial.print(pct);
      Serial.print(F("% "));
      if (cur_sec < 10) Serial.print(' ');
      Serial.print(cur_sec);
      Serial.println('s');
      
      hits = 0;
      samples = 0;
    }
    last_sec = cur_sec;
  }

  digitalWrite(NRF_CE_PIN, LOW);
  SPI.endTransaction();
  SPI.end();
  
  Serial.println(F("=============================="));
}
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
void loop() {
  // Check 3-position hardware switch state
  bool switch_pos1 = (digitalRead(HW_SWITCH_PIN) == LOW);  // D2 LOW = position 1
  bool switch_pos3 = (digitalRead(HW_SWEEP_PIN) == LOW);   // D3 LOW = position 3
  
  // --- Position 1: Full spectrum ---
  if (switch_pos1 && !hw_jamming_active) {
    cancel_adaptive();
    if (hw_sweep_active) {
      hw_sweep_active = false;
      sweep_active = false;
      send_cmd_all(MODE_SWEEP, 0, CMD_STOP);
    }
    hw_jamming_active = true;
    current_mode = MODE_FULL_SPECTRUM;
    selected_channel = 0;
    send_cmd_all(MODE_FULL_SPECTRUM, 0, CMD_START);
    jamming_active = true;
    Serial.println(F("\n[HW] Pos 1 - full spectrum jamming"));
  } else if (!switch_pos1 && hw_jamming_active) {
    hw_jamming_active = false;
    send_cmd_all(current_mode, selected_channel, CMD_STOP);
    jamming_active = false;
    Serial.println(F("\n[HW] Switch OFF"));
  }
  
  // --- Position 3: Sweep (only if position 1 is not active) ---
  if (!hw_jamming_active) {
    if (switch_pos3 && !hw_sweep_active) {
      cancel_adaptive();
      hw_sweep_active = true;
      current_mode = MODE_SWEEP;
      sweep_channel = 1;
      selected_channel = 1;
      last_sweep_ms = millis();
      send_cmd_all(MODE_SWEEP, 1, CMD_START);
      jamming_active = true;
      Serial.println(F("\n[HW] Pos 3 - sweep mode"));
    } else if (!switch_pos3 && hw_sweep_active) {
      hw_sweep_active = false;
      sweep_active = false;
      send_cmd_all(MODE_SWEEP, 0, CMD_STOP);
      jamming_active = false;
      Serial.println(F("\n[HW] Switch OFF"));
    }
  }
  
  // Sweep timer: advance channel periodically
  if ((sweep_active || hw_sweep_active) && jamming_active) {
    if (millis() - last_sweep_ms >= sweep_dwell_ms) {
      last_sweep_ms = millis();
      advance_sweep();
    }
  }
  
  // Pattern timing for pulsed/burst (master-driven START/STOP)
  if (jamming_active && !hw_jamming_active && !hw_sweep_active && !sweep_active && (current_pattern == 1 || current_pattern == 3)) {
    uint32_t now = millis();
    if (pattern_state && now - pattern_timer >= pattern_on_ms) {
      if (current_mode == MODE_CUSTOM) send_custom_cmds(CMD_STOP);
      else send_cmd_all(current_mode, selected_channel, CMD_STOP);
      pattern_state = false;
      pattern_timer = now;
    } else if (!pattern_state && now - pattern_timer >= pattern_off_ms) {
      if (current_mode == MODE_CUSTOM) send_custom_cmds(CMD_START);
      else send_cmd_all(current_mode, selected_channel, CMD_START);
      pattern_state = true;
      pattern_timer = now;
    }
  }
  
  if (Serial.available()) {
    String cmdLine = Serial.readStringUntil('\n');
    executeCommand(cmdLine);
    delay(10);  // Small delay after command processing (WARN-1 fix)
  }
  
  if (jamming_active && millis() - last_status_ms >= STATUS_INTERVAL_MS) {
    last_status_ms = millis();
    poll_slaves();
  }

  if (adaptive_active && jamming_active && millis() - last_adaptive_ms >= (uint32_t)adaptive_interval_sec * 1000) {
    cmd_adaptive();
  }
}

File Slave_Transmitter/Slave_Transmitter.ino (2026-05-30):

/**
 * Slave_Transmitter.ino
 * 
 * Slave NRF24L01+ transmitter for distributed Wi-Fi jamming.
 * Receives channel/mode/start-stop commands via I2C and jams
 * using NRFLite with NO_ACK packets on the specified frequency.
 * Targets: MH-Tiny ATtiny88 (ATTinyCore attinyx8micr) or
 *          Digispark ATtiny85 (ATTinyCore attinyx5micr).
 * 
 * Memory budget (ATtiny88): 512B RAM, 6780B Flash
 * Optimization target: <256B RAM to leave headroom for stack
 * 
 * Serial debugging via SoftwareSerial on PD0(RX)/PD1(TX) - connect FTDI adapter
 */
#include <NRFLite.h>
#include <SPI.h>
#include <Wire.h>

#define SLAVE_ID 0
#define I2C_ADDR (0x01 + SLAVE_ID)

// Mode constants (must match Master_Controller.ino)
#define MODE_SINGLE_CHANNEL 1
#define MODE_FULL_SPECTRUM 2
#define MODE_CUSTOM 3
#define MODE_SWEEP 4
#define CMD_START 1
#define CMD_STOP 0

#define CE_PIN  9
#define CSN_PIN 10
#define LED_PIN 0   // Red RX LED on MH-Tiny (D0/PD0)

// Protocol constants
#define PACKET_SIZE 6
#define MAX_FREQ_OFFSET 83
#define TOTAL_SLAVES 12

// Compile-time guard: local_idx and group_size are packed into 4-bit nibbles (max 15)
// See FANOUT_* macros and Master_Controller.ino send_cmd() byte 4 packing
#if TOTAL_SLAVES > 15
#error "TOTAL_SLAVES exceeds 15 - nibble packing in fanout byte will overflow"
#endif

// Separate current/pending state to avoid race conditions (CRIT-2 fix)
// ISR writes to pending_*, loop() copies to current_* under cli() protection
static volatile uint8_t pending_flags = 0;    // bit 0: jamming, bit 1: has_pending
static volatile uint8_t pending_mode = 0;
static volatile uint8_t pending_channel = 0;
static volatile uint8_t pending_fanout = (TOTAL_SLAVES);  // packed: local_idx<<4 | group_size
static volatile uint8_t pending_power = 3;  // 0=MIN, 1=LOW, 2=HIGH, 3=MAX

static uint8_t current_mode = 0;
static uint8_t current_channel = 0;
static uint8_t current_fanout = (TOTAL_SLAVES);  // packed: local_idx<<4 | group_size
static uint8_t current_power = 3;  // 0=MIN, 1=LOW, 2=HIGH, 3=MAX

static volatile uint8_t pending_pattern = 0;
static uint8_t current_pattern = 0;

static uint8_t noise_buf[32];

// Unpack fanout: local_idx from high nibble, group_size from low nibble
#define FANOUT_LOCAL_IDX(f)  ((f) >> 4)
#define FANOUT_GROUP_SIZE(f) ((f) & 0x0F)

#define FLAG_JAMMING    0x01
#define FLAG_PENDING    0x02

NRFLite radio;

// Fast 8-bit LFSR for noise generation (faster than random())
static uint8_t lfsr = 0xAC;  // Non-zero seed
#define LFSR_NEXT() (lfsr = (lfsr >> 1) ^ (-(lfsr & 1u) & 0xB8))

static void slave_set_power(uint8_t level) {
  if (level > 3) level = 3;
  digitalWrite(CSN_PIN, LOW);
  SPI.transfer(0x20 | 0x06);
  SPI.transfer(0x09 | (level << 1));
  digitalWrite(CSN_PIN, HIGH);
}

/**
 * Fast RF channel change - writes only RF_CH register without full radio init.
 * Used by sweep mode (mode=4) for rapid channel cycling (~microseconds vs ~100ms).
 */
static void set_nrf_channel(uint8_t freq) {
  if (freq > MAX_FREQ_OFFSET) freq = MAX_FREQ_OFFSET;
  digitalWrite(CSN_PIN, LOW);
  SPI.transfer(0x20 | 0x05);
  SPI.transfer(freq);
  digitalWrite(CSN_PIN, HIGH);
}

/**
 * Calculate NRF24 channel (frequency offset from 2400 MHz)
 * Uses local fan-out formula: center + (local_idx * 2) - (group_size - 1)
 * 
 * @param mode: 1/3 = Single/Custom (fan-out), 2 = Full Spectrum
 * @param ch: Wi-Fi channel (1-13)
 * @param local_idx: Local index within channel group (0 to group_size-1)
 * @param group_size: Number of slaves in this channel group
 * @return: NRF24 channel (0-83)
 * 
 * Worked example (Single Channel mode, ch=6, 3 slaves on channel):
 *   center = 7 + ch*5 = 7 + 30 = 37  (Wi-Fi ch6 center is 2437 MHz)
 *   For slave with local_idx=0, group_size=3:
 *     offset = (0 * 2) - (3 - 1) = 0 - 2 = -2
 *     freq = 37 + (-2) = 35  => 2435 MHz
 *   For slave with local_idx=1, group_size=3:
 *     offset = (1 * 2) - (3 - 1) = 2 - 2 = 0
 *     freq = 37 + 0 = 37  => 2437 MHz (center)
 *   For slave with local_idx=2, group_size=3:
 *     offset = (2 * 2) - (3 - 1) = 4 - 2 = 2
 *     freq = 37 + 2 = 39  => 2439 MHz
 *   Result: 3 slaves spread evenly across 4 MHz band centered on ch6
 */
static uint8_t calc_freq(uint8_t mode, uint8_t ch, uint8_t local_idx, uint8_t group_size) {
  uint8_t freq;
  if (mode == MODE_SINGLE_CHANNEL || mode == MODE_CUSTOM || mode == MODE_SWEEP) {
    // center = 12 + (ch-1)*5 = 7 + ch*5
    // offset = (local_idx * 2) - (group_size - 1)
    // freq = center + offset
    int8_t offset = (local_idx << 1) - (group_size - 1);
    uint8_t center = 7 + (ch << 2) + ch;  // 7 + ch*5
    freq = center + offset;
  } else {
    // Full spectrum: 14 + local_idx*5  (staggered between channels for max coverage)
    freq = 14 + (local_idx << 2) + local_idx;
  }
  return (freq > MAX_FREQ_OFFSET) ? MAX_FREQ_OFFSET : freq;
}



/**
 * Transmit 32-byte noise burst
 * Uses static buffer to avoid stack overflow risk on 512B MCU (CRIT-3 fix)
 */
static void transmit_noise() {
  uint8_t *buf = noise_buf;
  uint8_t *p = buf;
  for (uint8_t i = 0; i < 16; i++) {
    *p++ = LFSR_NEXT();
    *p++ = LFSR_NEXT();
  }
  if (current_pattern == 2) {
    uint8_t base = calc_freq(current_mode, current_channel,
                             FANOUT_LOCAL_IDX(current_fanout),
                             FANOUT_GROUP_SIZE(current_fanout));
    uint8_t r = lfsr & 0x03;  // 0-3
    int8_t offset = (int8_t)(r & 0x02 ? (int8_t)r - 3 : (int8_t)r);  // 0, 1, -1, 0 → avg 0
    uint8_t freq = base + offset;
    if (freq > MAX_FREQ_OFFSET) freq = MAX_FREQ_OFFSET;
    set_nrf_channel(freq);
  }
  radio.send(255, buf, 32, NRFLite::NO_ACK);
}
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

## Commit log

2026-05-30 Port slave from RF24 to NRFLite to fit ATtiny88 RAM; add Makefile and docs
    - Slave_Transmitter: replace RF24 with NRFLite (lighter library)
    ATtiny88: 4538B flash (66%), 290B RAM (56%) — 222B free, down from 566B over
    ATtiny85: 4234B flash (64%), 153B RAM (29%) — 359B free
    - Master_Swarm_Controller: doc comment improvements, fix compile errors
    - Add Makefile with multi-target compile/upload (master, slave-attiny88, slave-attiny85)
    - Add README.md, USAGE.md, WIRING.md documentation
    [Master_Swarm_Controller.ino, Slave_Transmitter.ino]
2026-05-30 Update docs for NRFLite migration and MH-Tiny hardware
    - README: fix BOM (MH-Tiny slaves, not Nano), slave hardware refs,
    RF24->NRFLite deps, self-test output, add Makefile build section
    - WIRING.md: MH-Tiny slave pinout diagrams, SDA/SCL pin clarification
    - .context.md: NRFLite init flow, remove RF24 C++11 workarounds
2026-05-30 WIRING: fix slave labels to MH-Tiny, correct SDA/SCL pin mapping
2026-05-30 WIRING: fix ASCII art box alignment, update I2C topology labels
2026-05-30 WIRING: wrap ASCII art in fenced code blocks
    Each ASCII diagram section (System Overview, Master, Slave, I2C Topology,
    NRF24 Module Pinout, Power Distribution) is now inside triple-backtick
    fences so GitHub renders them as monospace pre blocks instead of
    misinterpreting | / + characters as table syntax.
2026-05-30 WIRING: fix Slave #11 I2C address 0x0C -> 0x0B, clean up ASCII art
2026-05-30 WIRING: pad Master Node ASCII art inner box by 1 space
2026-05-30 WIRING: revert Slave #11 to 0x0C
2026-05-30 WIRING: remove extra table row, space out checklist items
2026-05-30 WIRING: convert checklist to bullet list
2026-05-30 WIRING + USAGE: manual edits
2026-05-30 Manual edits to README, USAGE, WIRING
2026-05-30 README: add CH340 driver install instructions for macOS/Windows/Linux
2026-05-30 README: add arduino-cli platform core and library install commands
2026-05-30 Drop RF24 dependency: remove unused NRF24L01+ RX code from master, update README/BOM
2026-05-30 WIRING+README: remove master NRF24 references after RF24 dep removal
2026-05-30 Revert WIRING.md: NRF24 hardware is still physically wired
2026-05-30 README: restore NRF24 module in master BOM/hardware list
2026-05-30 README: separate MH-Tiny and Nano slave rows in BOM
2026-05-30 WIRING: add NRF24 decoupling caps diagram and detailed battery/buck/100uF power diagram
2026-05-30 WIRING: fix decoupling caps diagram — parallel not series
2026-05-30 WIRING: manual edits
2026-05-30 WIRING: align 5V/GND rail labels in power diagram
2026-05-30 WIRING: center-align master node box in system overview
2026-05-30 Slave: defer radio.init to loop() to avoid SPI in I2C interrupt
    [Slave_Transmitter.ino]
2026-05-30 Master: periodic I2C poll of slave jamming status every 5s
    [Master_Swarm_Controller.ino]
2026-05-30 NRFLite unification, channel fan-out, major optimizations
    - Switch all 13 units to NRFLite library (simpler codebase)
    - Implement channel fan-out: spread 12 slaves across 22MHz width at 2MHz spacing
    - Update I2C protocol: byte 4 carries slave_id (0-11) for fan-out calc
    Optimizations (Slave ATtiny88):
    - Flash: 64% -> 50% (-22%), RAM: 63% -> 49% (-33%)
    - Consolidated volatile state with proper cli()/SREG atomic protection
    - LFSR noise generation replaces slower random()
    - 4x loop unrolling in hot jamming path
    - DEBUG_SERIAL flag for production builds
    Optimizations (Master Nano):
    - Flash: 38% -> 32% (-16%), RAM: 74% -> 21% (-71%)
    - Packed slave config: 48-byte struct -> 12-byte array with mac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
    [Master_Swarm_Controller.ino, Slave_Transmitter.ino]
2026-05-30 Implement local fan-out indexing for balanced channel coverage
    Each channel group now independently centers around its peak frequency
    instead of using global slave_id which caused unbalanced distribution.
    Protocol change (I2C byte 4):
    - Old: slave_id (0-11)
    - New: packed local_idx (high nibble) | group_size (low nibble)
    New formula: center_freq + (local_idx * 2) - (group_size - 1)
    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
2026-05-30 Add hardware switch, RF scanning, and improved serial UI
    - Hardware switch on D2 enables full-spectrum jamming (takes precedence over software)
    - NRF24L01+ startup check verifies module is working
    - New 'snap' command: RF snapshot of all channels with configurable collection time
    - New 'scan <ch> [time]' command: live waterfall scan of a single channel
    - Improved serial output formatting with consistent borders
    - Updated Makefile: auto-detect port, arduino-cli monitor, USBasp ISP upload
    - Added NRF_Tester sketch for testing NRF modules
    - PCB designs: slave carrier board and master+power board (Gerbers ready)
    - Updated README with new features and commands
    [master-B_Adhesive.gbr, master-B_Courtyard.gbr, master-B_Cu.gbr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]
2026-05-30 Add TODO.md with feature roadmap; rename snap to snapshot
    [Master_Swarm_Controller.ino]
2026-05-30 Add power level command (1-4) with I2C 5th byte protocol
    Master: power command sets TX power sent as 5th I2C byte
    Slave: direct RF_SETUP register write after radio.init()
    Default: MAX (4)
2026-05-30 Fix CRITICAL bug: slave never stops on CMD_STOP; fix remaining review issues
    - CRITICAL: Slave loop() now checks FLAG_JAMMING. Previously checked current_mode which stayed non-zero on CMD_STOP — slaves jammed forever
    - Fix slave LFSR random hop offset bias (avg +1 -> avg 0)
    - Fix print_freq_map() showing wrong mode/freqs during MODE_SWEEP
    - Fix double 'turn switch off' message (removed from cancel_adaptive)
    - Remove dead cancel_sweep() code
    - Add cancel_adaptive() + hw_sweep_active check to adaptive command
    - Add Slave_Transmitter/build/ and .history to gitignore
    - Add OPTIMIZE.md, REVIEW.md
    [Master_Controller.ino, Slave_Transmitter.ino]
2026-05-30 Update Power Configuration section for adjustable power levels
2026-05-30 Remove TODO.md — all tasks complete
2026-05-30 Update status output examples and clarify NRF24 power wiring
    - Rewrite Example Status Outputs section to match current firmware's
    print_status() + print_freq_map() format (includes sweep, adaptive,
    and hardware switch examples)
    - Fix Full Spectrum frequency values from 2415-2470 to 2414-2469 MHz
    to match actual code formula (14 + local_idx * 5)
    - Add note clarifying that NRF24L01+ breakout boards with onboard 3.3V
    LDO accept 5V input (important for MH-Tiny slaves)
